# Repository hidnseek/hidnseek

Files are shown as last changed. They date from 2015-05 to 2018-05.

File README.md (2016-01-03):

# hidnseek
## The smart, Accurate GPS tracker on sigfox network
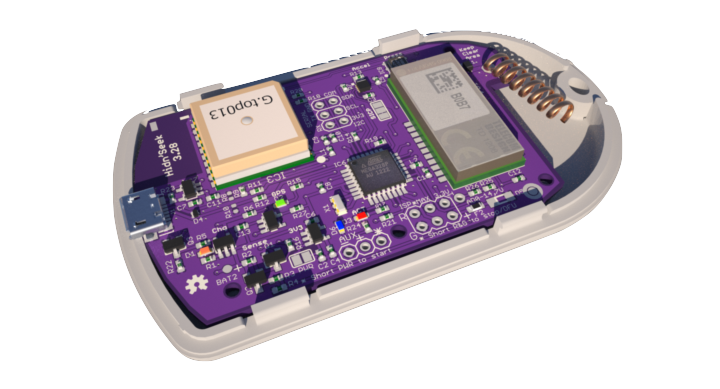
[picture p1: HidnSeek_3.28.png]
Inside Board View


* true GPS localisation
* 3 axis Motion sensor
* Temperature and Pressure data logger
* Several months autonomous
* Rechargeable and monitored battery
* Firmware update with onchip USB interface
* Geo Fencing with [Apple iOS](https://itunes.apple.com/fr/app/hidnseek/id1014592720?mt=8) and [Android](https://play.google.com/apps/testing/com.hidnseek.hidnseek) Application
* GPIOs available for future extensions (i2c, Serial, ISP, Analog input, Digital)

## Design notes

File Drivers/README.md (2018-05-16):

### Arduino IDE Setup

The first thing you will need to do is to download the latest release of the Arduino IDE. You will need to be using version **1.6.4** or higher for this guide.

[Arduino IDE v1.6.x](http://www.arduino.cc/en/Main/Software)

After you have downloaded and installed **v1.6.11**, you will need to start the IDE and navigate to the **Preferences** menu. You can access it from the **File** menu in Windows or Linux, or the **Arduino** menu on OS X.

A dialog will pop up and we will be adding a URL to the new **Additional Boards Manager URLs** option. The list of URLs is comma separated, and you will only have to add each URL once. New HidnSeek board and update to existing boards will automatically be picked up by the Board Manager each time it is opened. The URLs point to index files that the Board Manager uses to build the list of available & installed boards.
To find the most up to date list of URLs you can add, you can visit the list of [third party board URLs on the Arduino IDE wiki](https://github.com/arduino/Arduino/wiki/Unofficial-list-of-3rd-party-boards-support-urls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). We will only need to add one URL to the IDE in this example, but **you can add multiple URLS by separating them with commas**. Copy and paste the link below into the **Additional Boards Manager URLs** option in the Arduino IDE preferences.

[https://hidnseek.github.io/hidnseek/package_hidnseek_boot_index.json](https://hidnseek.github.io/hidnseek/package_hidnseek_boot_index.json)

Click **OK** to save the new preference settings. Next we will look at installing boards with the Board Manager.

### Installing Boards

Now that you have added the appropriate URLs to the Arduino IDE preferences, you can open the **Boards Manager** by navigating to the **Tools->Board** menu. Find and install **HidnSeek** board.

Next, **quit and reopen the Arduino IDE** to ensure that all of the boards are properly installed. You should now be able to select and upload to the new boards listed in the **Tools->Board HidnSeek** menu.

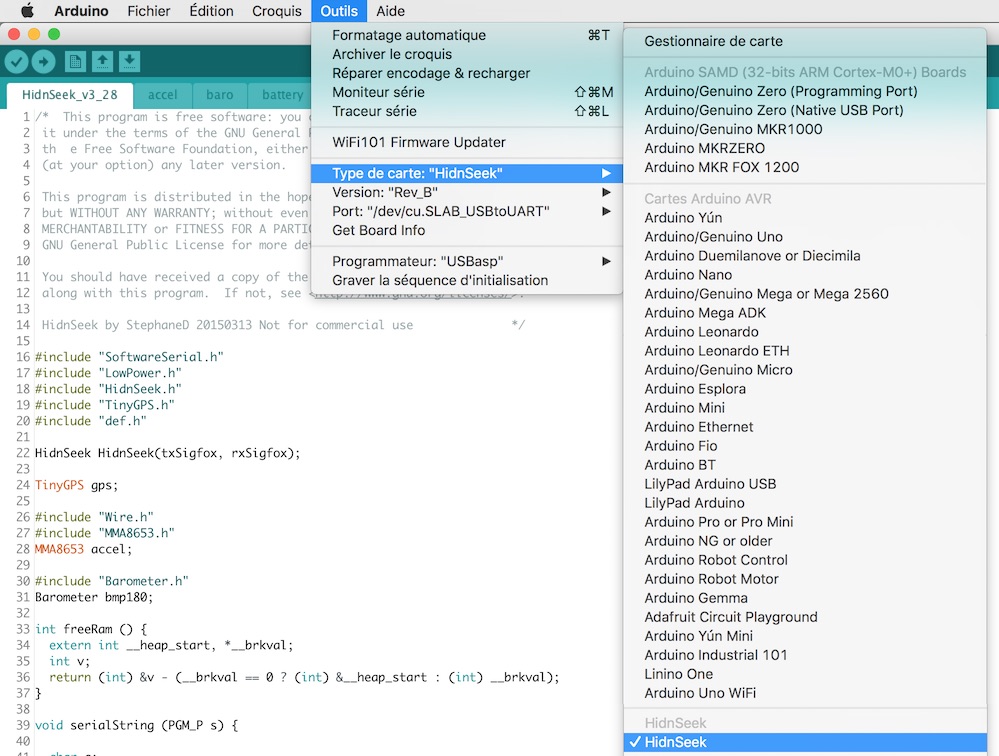
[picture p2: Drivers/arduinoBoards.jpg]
alt arduino Boards image


### USBasp Drivers for Windows
* **Windows up to 7.x** : [usbasp-windriver.2011-05-28.zip](usbasp-windriver.2011-05-28.zip)
* **Windows 8.1 to 10.x** : [USBasp-win-driver-x86-x64-v3.0.7.zip](USBasp-win-driver-x86-x64-v3.0.7.zip)

The USBASP windows driver was previously based on libusb-win32. The certificate on the base drivers have expired and the library has now been superseded by libusbK. Earlier today we packaged up the driver and uploaded it to the server. You can now download it from the location below.

 [http://www.protostack.com/download/USBasp-win-driver-x86-x64-v3.0.7.zip] (http://www.protostack.com/download/USBasp-win-driver-x86-x64-v3.0.7.zip)
 
This driver should work with version of Windows XP right through to 8.1 and the version 10 preview. (both 32 and 64 bit editions). Because the driver is signed, there should be no need to disable driver certificate enforcement or use Zadig.

### Update Febuary 16 to upgrade the firmware with hex provided on the website

first, power off the hidnSeek tracker (dance on manual page 16 or short circuit R&G pins)

* On Windows 10, install the executable version of [Arduino IDE v1.8.x](http://www.arduino.cc/en/Main/Software)
not the Windows App version.

* install the driver from Zadig [http://zadig.akeo.ie/downloads/zadig_2.2.exe] (http://zadig.akeo.ie/downloads/zadig_2.2.exe)

Launch the software, connect the tracker and click on the install button. It will detect the tracker and install correct drivers. Disconnect the tracker before Green LED start blinking, if it blink, power off again the tracker.

* Open a command windows (Win+X), go in the C:\Users\Program Files(x86)\Arduino\hardware\tools\avr\bin and prepare the command as above with a respect of the path of the hex file:

**avrdude -C ..\etc\avrdude.conf -p atmega328p -c usbasp -P usb -U flash:w:"C:\Users\[your path]\HidnSeek.hex":i**

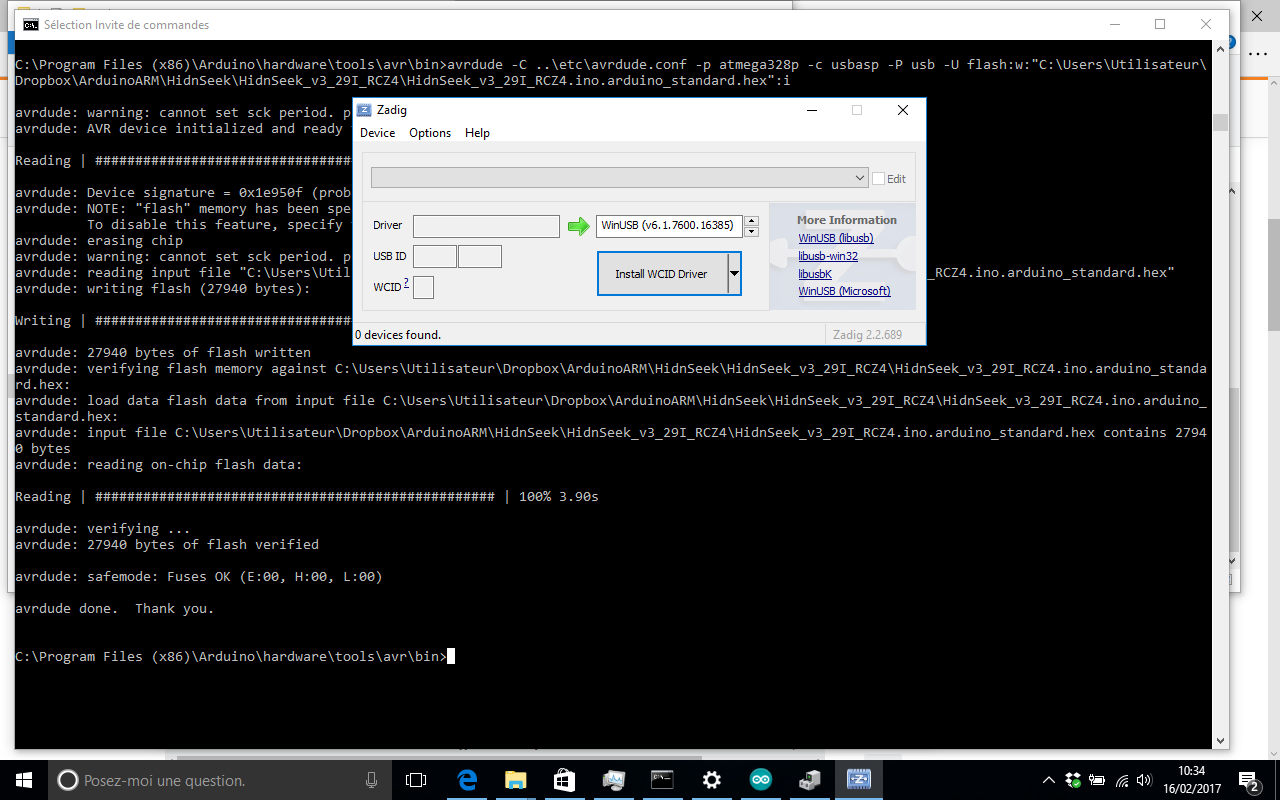
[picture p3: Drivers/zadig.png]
alt zadig image


When you are ready, connect the tracker to the USB port and launch the command. If there is an error, unplug the tracker to avoid to repeat the power off procedure.

### Reset manually the tracker

Unplug the USB connector, open the tracker and make a short-cut between R and G pins like the above picture.

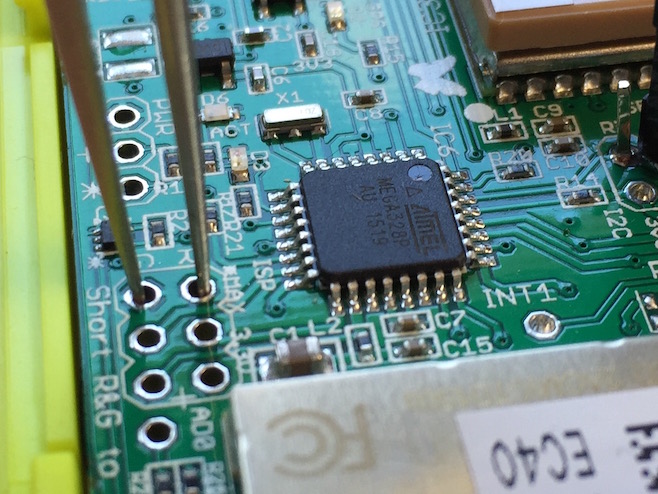
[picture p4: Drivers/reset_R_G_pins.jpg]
alt R and G picture hidnseek reset image


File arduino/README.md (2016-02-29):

#Arduino Hardware, source code and libraries

##Hardware : changes and needs for Arduino IDE 1.6.4 and higher
Go to the page [Drivers](/Drivers) in this repository and follow instructions

##Hardware : changes and needs for Arduino IDE

How to upload new firmware in Hidnseek ?

First install Arduino IDE (https://www.arduino.cc/en/Main/Software)
If Arduino IDE already installed, leave/exit the software.

Second, find in the installation directory the boards.txt file

* /Applications/Arduino.app/Contents/Java/hardware/arduino/avr/boards.txt (Mac)
* c:\Documents and Settings\<USERNAME>\Application Data\Arduino\hardware\arduino\avr\boards.txt (Windows XP)
* c:\Users\<USERNAME>\AppData\Roaming\Arduino\hardware\arduino\avr\boards.txt (Windows Vista)
* ~/.arduino/hardware/arduino/avr/boards.txt (Linux)

Insert at the end of this file the description of HidnSeek from [boards.txt](/Drivers/Hardware/boards.txt) 

##libraries : librairies used to compile the sketch

Copy all libraries in this repository that are not present in your libraries directory

##HidnSeek Sketch Examples

Launch Arduino IDE and go to the board selection and select HidnSeek at 12MHz

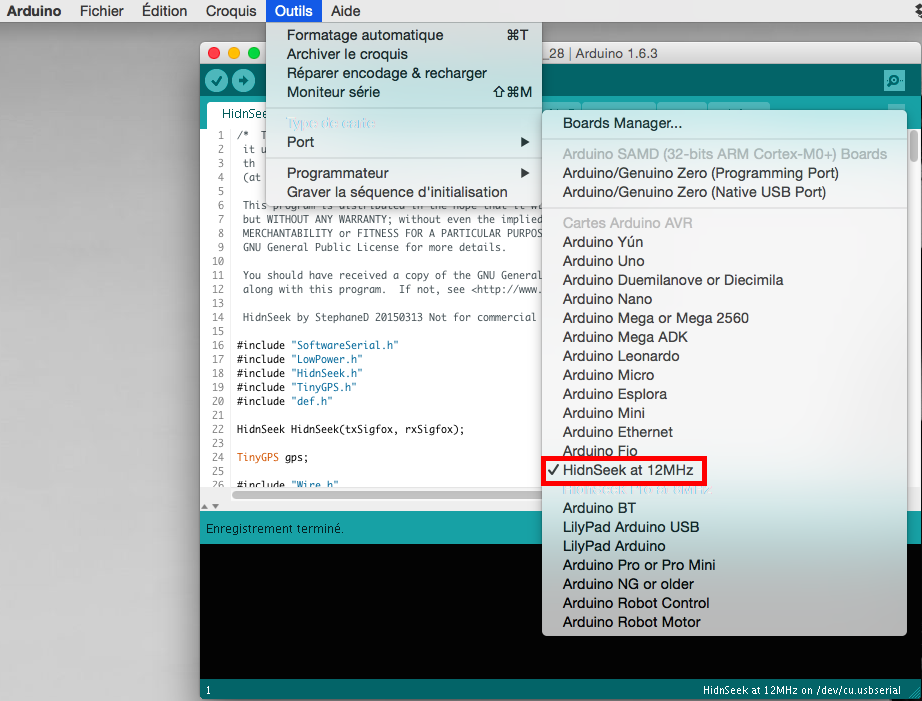
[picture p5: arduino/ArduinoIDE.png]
ArduinoIDE


Then select the programmator type USBasp

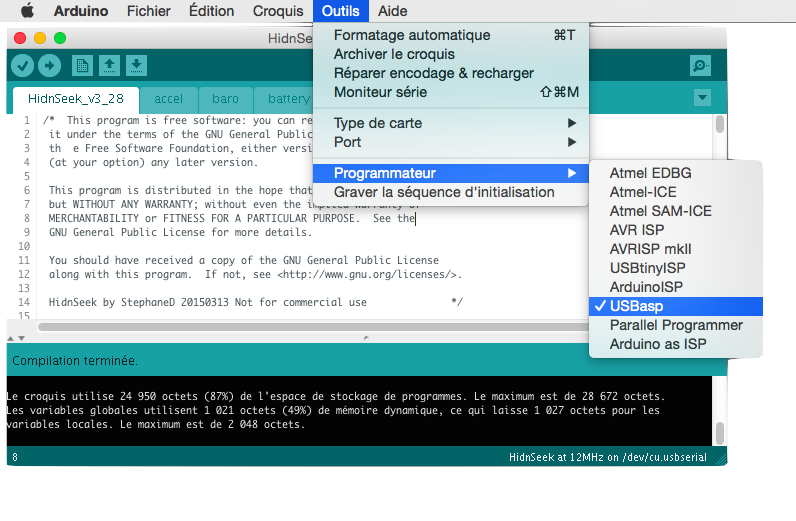
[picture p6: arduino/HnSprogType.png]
HnSprogType


Go to the Examples and select one of available in the HidnSeek tree (BlinkWithin30seconds, HidnSeek_v3_28 and detectMotion)

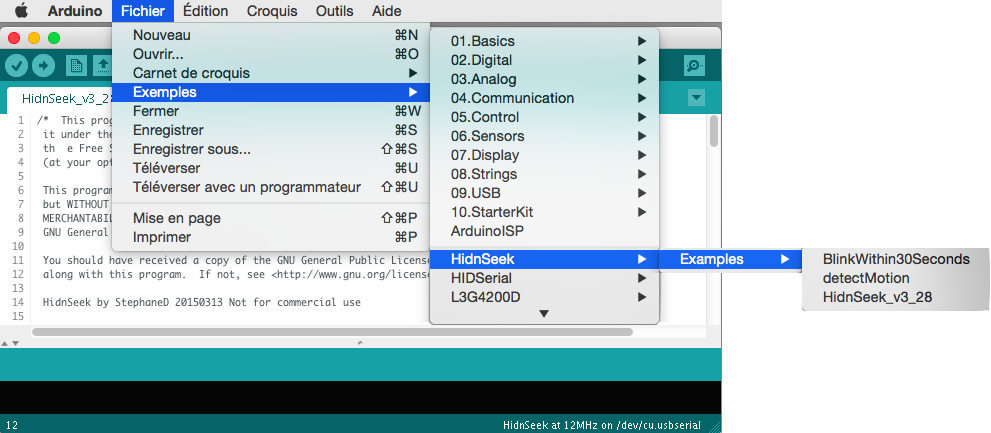
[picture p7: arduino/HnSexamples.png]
Examples


###HidnSeek_v3_28 of the 3.28 release board:
Load the sketch HidnSeek_v3_28 and compile it. The code size must be 24 950 bytes and available memory is 1027 bytes

There is two methods to prepare HidnSeek for DFU mode (firmware update)

1. make the dance that you can find on the manual or [FAQ](https://www.hidnseek.fr/faq)
2. make a short circuit between R & G pins (you will loose daily statistics)

Once it's done, you can plug the USB cable to the computer and the HidnSeek board.
You will see between 30 and 60 red LED flashes to notice that you are in DFU mode. Click on download on your sketch windows.
Firmware update will be transfered in less than 4 seconds. Do not care about the clk speed warning.
Your sketch is ready to start after the booting time (0-30) seconds

Have fun !

## Serial debugging

You can plug a USB Serial TTL dongle and get debug output from HidNseek on pin TX and output from GPS on RX. 

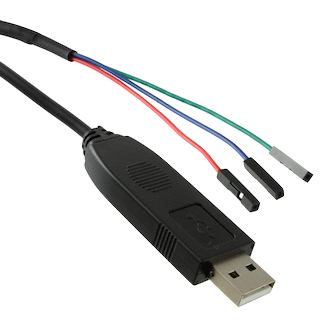
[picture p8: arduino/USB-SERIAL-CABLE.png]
USB cable
 | If GPS is not enabled, its output is floating and you can use that state to send serial data to HidnSeek **at 3,3V maximum !!!!**
------------- | -------------

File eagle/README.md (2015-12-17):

# hidnseek

Eagle libray for the HidnSeek and droneRescue Projects

- MMA8653 Freescale Accelerometer
- Molex 47346 Micro USB Connector
- Atmega 328p MLF32 Package with small Thermal Pad
- Murata Super Capacitor DMF3 Series
- Taiyo Yuden Coin Cell Super Capacitor
- Telecom Design TD120x SigFox Internet of Things Modem
- TPS2513 Texas Instrument Current Limited USB Charger Controller
- TPS2294x Texas Instrument Current Limited Power Switch

# Telecom Design breakout board
schematic and layout for Eagle software

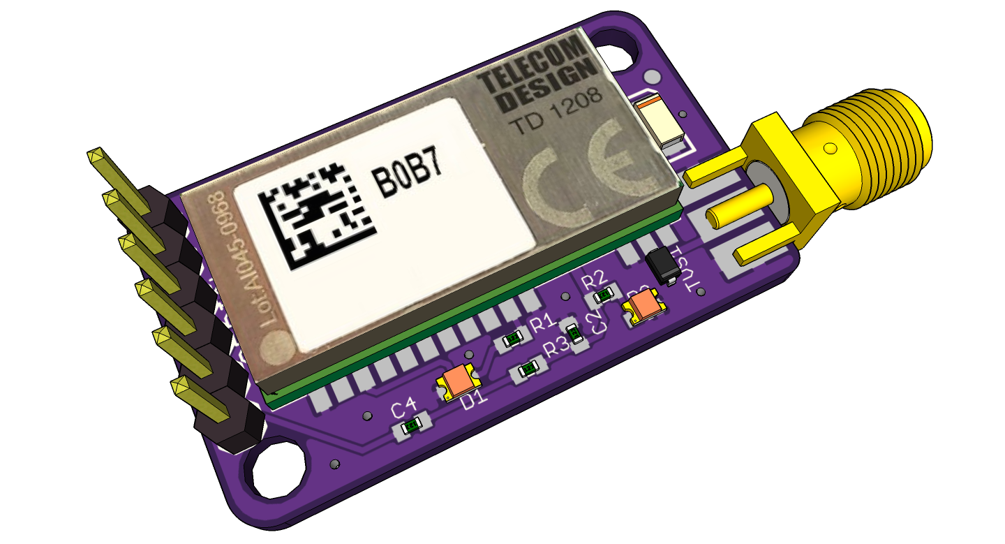
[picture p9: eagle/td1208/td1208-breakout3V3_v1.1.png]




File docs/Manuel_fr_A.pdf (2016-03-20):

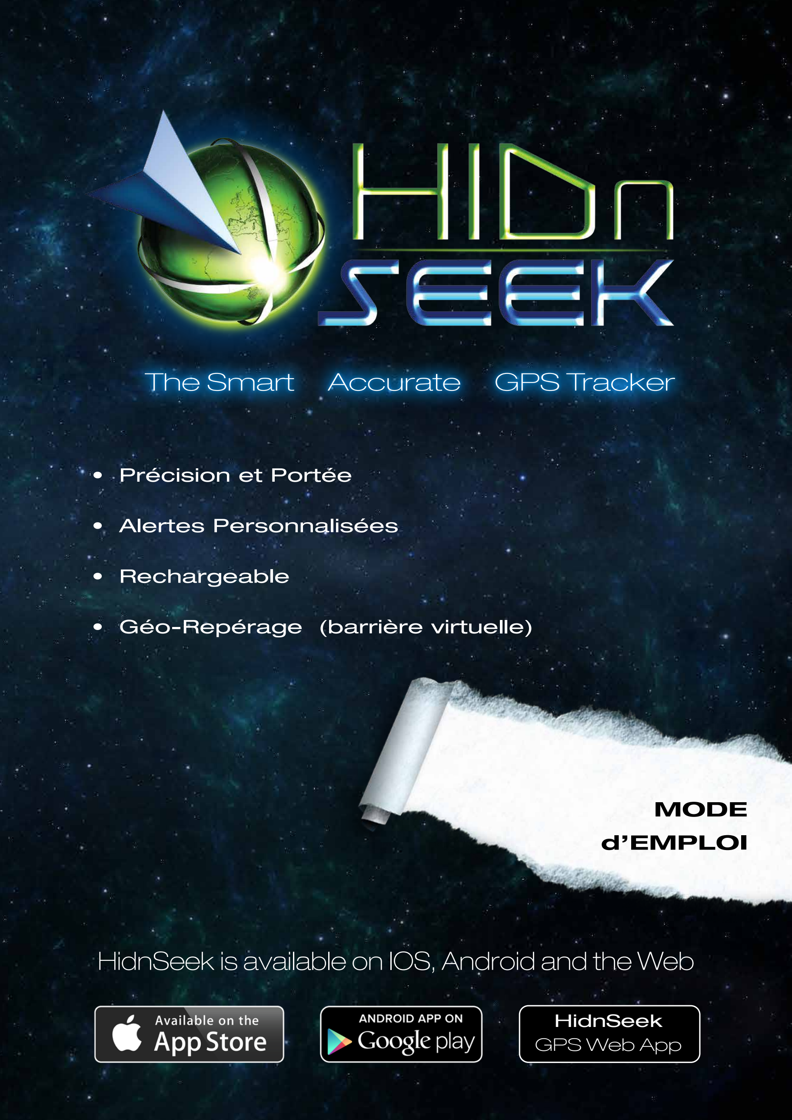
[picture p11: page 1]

## The Smart Accurate GPS Tracker

### MODE d’EMPLOI

## HidnSeek is available on IOS, Android and the Web

HidnSeek
GPS Web App
- Précision et Portée
- Alertes Personnalisées
- Rechargeable
- Géo-Repérage (barrière virtuelle)

# CONTENTS

Informations importantes concernant votre appareil. Compatibilité électromagnétique
Risques pour les enfants et les personnes ayant besoin de soins
Conseils de sécurité
Fonctionnement de la batterie
Disposition
Fonctions et utilisation
Déclaration de conformité
Rayonnement de la CE de la déclaration de l'exposition
CE radiation exposure statement
RSS (catégorie | équipement)

Guide d'installation rapide

Commencer
Se charge
Activation
L'App

Smartphone App Utilisation Se connecter
Rajout / Eacer un Device
Location
Ecran d’information HidnSeek Conguration des Alertes
Renommez dispositif
Niveau de la batterie
Détection de mouvement
Géo-Barrière (Geo-fencing) Créer un Géo-fence
Eacer un Géo-fence
Paramètres Géo-fencing
Ecran d’Alertes

Mise HidnSeek Arrêt / Marche

Mode Sport

Presentation de votre appareil

LED et état de l'appareil

Soutien

Page 3

Page 4

Page 5

Page 6

Page 7

Page 8

Page 9

Page 10
Page 11
Page 12

Page 13

Page 14

Page 15

Page 16

Page 17

Page 18

## INFORMATIONS IMPORTANTES

CONCERNANT VOTRE APPAREIL.

COMPATIBILITÉ ÉLECTROMAGNÉTIQUE
Les champs magnétiques intensifs (par ex. des transformateurs) doivent être strictement évités, sinon des écarts dans la transmission peuvent apparaître. Ignorer les instructions d’utilisation peut entraîner une perturbation ou des dommages du dispositif de repérage GPS HidnSeek.

DANGERS POUR LES ENFANTS ET LES PERSONNES AYANT DES CAPACITÉS RÉDUITES
Cet appareil n’est pas destiné à être utilisé par des personnes (y compris les enfants) ayant des capacités physiques, sensorielles ou mentales limitées, ou manquant d’expérience et/ ou de connaissances, sauf si elles sont surveillées par une personne responsable de leur sécurité ou ont reçu des instructions sur la façon d’utiliser cet appareil.

RENSEIGNEMENTS SUR LA SÉCURITÉ
Attention: Bien que le dispositif de repérage HidnSeek soit petit et de faible poids, il peut être trop lourd pour hurter les enfants ou animaux.

MODE BATTERIE
Le dispositif de repérage HidnSeek fonctionne avec une batterie au lithium-polymère rechargeable intégrée qui ne peut pas être échangée:
- La batterie du dispositif de repérage GPS HidnSeek ne peut pas être échangée et ne doit pas être retirée.
- Ne laissez pas le dispositif de repérage GPS HidnSeek à proximité d’une source de chaleur ou dans un lieu où la température est très élevée, par exemple dans un véhicule stationné en plein soleil.
- Le dispositif de repérage GPS HidnSeek ne doit pas être percé ou brûlé.
- Chargez la batterie exclusivement avec le câble USB fourni. Si la batterie est chargée différemment, une surchauffe, un incendie ou une explosion peuvent être provoqués.
- Ne chargez pas la batterie du dispositif de repérage GPS Tractive à proximité d’une source de chaleur ou dans une voiture stationnée en plein soleil. La température élevée peut provoquer la destruction de la batterie et peut causer une surchauffe, une explosion ou un feu.
Le non-respect de ces instructions peut raccourcir la durée de vie de la batterie intégrée ou endommager le dispositif de repérage HidnSeek.

RENSEIGNEMENT: Dans certains pays et régions, il y a des lois sur le positionnement numérique et le suivi des personnes, des animaux et/ou des objets. Seul l’utilisateur du dispositif de repérage GPS HidnSeek, est responsable de ne pas violer ces lois ou règles. HidnSeek ne peut en aucun cas porter cette responsibilité.used.

DISPOSITION
Les batteries usagées sont considérées comme des déchets dangereux. Si vous souhaitez jeter la batterie, veuillez vous rendre chez un revendeur de piles ou dans des endroits de collecte qui mettent à votre disposition des collecteurs réservés à cet effet. Si vous souhaitez jeter votre appareil, éliminez-le selon la réglementation actuelle. Vous pouvez obtenir des renseignements relatifs au recyclage des batteries auprès des municipalités.

FONCTIONS ET UTILISATION
Afin de permettre la localisation des personnes ou possessions, vous avez besoin d’un ordinateur avec accès à l’Internet et/ou d’un Smartphone (Android, iPhone) ainsi que l’application HidnSeek GPS correspondante, disponible dans l’Apple App Store ou sur Google Play Store. Le dispositif de repérage GPS HidnSeek peut être utilisé seulement après l’activation réussie sur un navigateur.

AFIN DE RESPECTER LES AUTORITES AERONOTIQUE, ETEINDRE VOTRE HIDNSEEK AVANT LE DECOLLAGE CAR CELUI-CI PEUT CAUSER DES INTERFERENCES ELECTROMAGNETICS AUX SYSTEMES DE NAVIGATION DE L’AVION.

HIDNSEEK EST UN APPAREIL “SIGFOX READY” QUI A BESOIN DU RESEAU SIGFOX POUR FONCTIONNER

DÉCLARATION DE CONFORMITÉ
EMC Directive 1999/519/CE:
Texte court de la déclaration: HidnSeek déclare que le dispositif de repérage GPS est conforme aux exigences essentielles et aux autres dispositions pertinentes de la directive 1999/519/CE.
EN 60950-1 (2006+A11/2009+A1/2010+A12/2011) IEC 60950-1 (2005+A1/2009) ETSI EN 300 220-1 V2.4.1 (2012)
ETSI EN 300 220-2 V2.4.1 (2012)
RECOMMENDATION DU CONSEIL N° 1999/519/CE of 12 July 1999
ETSI EN 301 489-1 (V1.9.2) - ETSI EN 301 489-3 (V1.6.1)

CE CERTIFICATION
Ce produit repond aux regles CE. Son fonctionnement est soumis aux 2 conditions suivantes:
1. Ce dispositif ne peut causer des interférences nuisibles et
2. Cet appareil doit accepter toute interférence reçue, y compris les interférences qui peuvent entraîner un mauvais fonctionnement de l’appareil.

AVERTISSEMENT: Les changements ou modifications de cette unité non expressément approuvés par le partie responsable de la conformité pourraient annuler l'autorité de l'utilisateur à utiliser cet équipement.

NOTE: Cet équipement a été testé et trouvé conforme aux limites pour ETSI EN 300 220-1 V2.4.1 (2012), ETSI EN 300 220-2 V2.4.1 (2012), en vertu de la règles CE. Ces limites sont conçues pour fournir une protection raisonnable contre les interférences nuisibles dans une installation résidentielle. Cet équipement génère, utilise et peut rayonner de l'énergie radiofréquence et, si non installé et utilisé en conformité avec les instructions, peut causer des interférences nuisibles aux communications radio. Cependant, il n'y a aucune garantie que l'interférence ne se produira pas dans une installation articuliere. Si cet équipement cause des interférences nuisibles à la réception radio ou la télévision, l'utilisateur est encouragé à essayer de corriger l'interférence par une ou plusieurs des mesures suivantes les mesures:
- Réorienter ou déplacer le tracker GPS,
- Augmenter la séparation entre l'équipement et le récepteur.
- Consulter le revendeur ou un technicien radio / TV expérimenté.

CE EXPOSITION AUX RADIATIONS
Cette exigence est conforme aux limites d'exposition aux radiations définies par la norme CE pour un environnement non contrôlé. Cet équipement doit être installé et utilisé avec distance minimum de 20cm entre le radiateur et votre corps. Cet émetteur ne doit pas être co-localisées ou opérant en conjonction avec tout autre antenne ou émetteur.

RSS (EQUIPEMENT I CATEGORIE)
Cet appareil est conforme avec Industrie France licence - standard RSS exonéré (s). Son fonctionnement est soumis aux deux conditions suivantes:
1. ce dispositif ne peut pas provoquer d'interférences et
2. ce dispositif doit accepter toute interférence, y compris les interférences qui peuvent causer un fonctionnement indésirable de l'appareil.

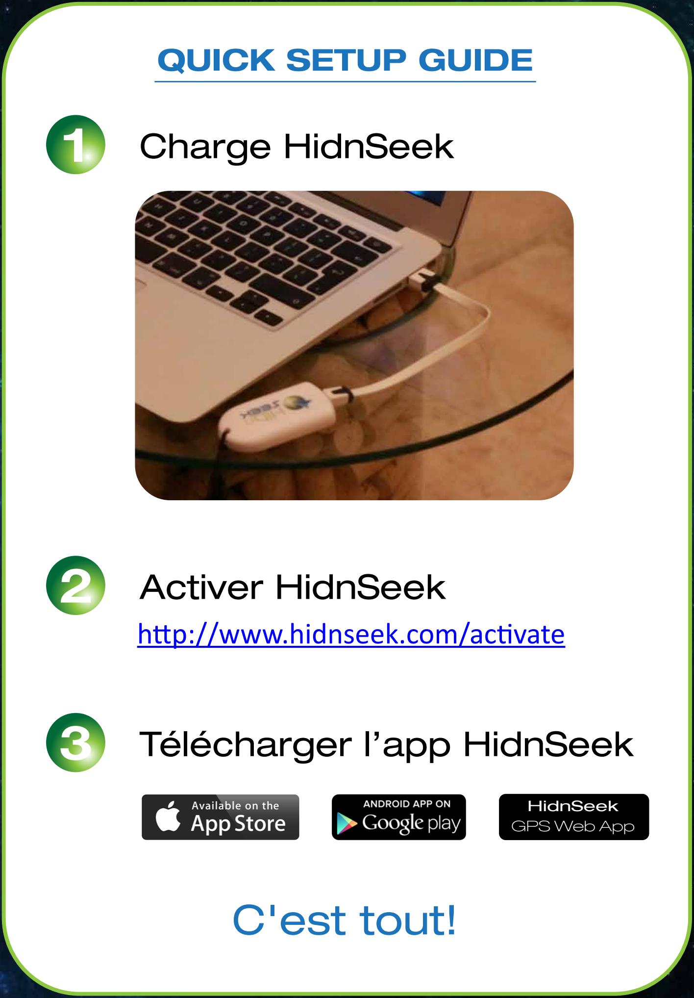
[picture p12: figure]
1 Charge HidnSeek; 2 Activer HidnSeek; 3 Télécharger l’app HidnSeek; QUICK SETUP GUIDE; C'est tout!; HidnSeek GPS Web App; http://www.hidnseek.com/activate

1

2

3

# COMMENCER

## COMPOSANTS DE LA COMMANDE 1 HidnSeek GPS Device 1 USB Charging Cable

## Se charge

Nous recommandons de charger l’appareil complètement avant la première utilisation. Branchez le câble micro-USB de chargement fourni avec l’appareil et connecter le cable sur votre PC pour recharger votre HidnSeek.

Lorsque votre produit HidnSeek est en charge une LED jaune s’allume. Lorsque votre HidnSeek est completement recharge la LED jaune s’etteind.

## Activer HidnSeek Pour activer le dispositif, il faut que l’appareil soit

allumé.

## Insérez le lien suivant dans la barre d’adresse de votre navigateur et rendez vous sur le site Internet d’HidnSeek, qui vous conduira étape par étape pour activer votre dispositif de repérage GPS HidnSeek:

## L'App Pour télécharger l'application à partir de l'iPhone d'Apple, charger l'iTunes App Store et de recherche pour 'HidnSeek'. Alternativement, si vous utilisez un Android, ouvrir le Google Play Store et commencer

une recherche pour 'HidnSeek'.

## http://www.hidnseek.com/activate

# SMARTPHONE APP UTILISATION

REJOINDRE | HIDNSEEK | –

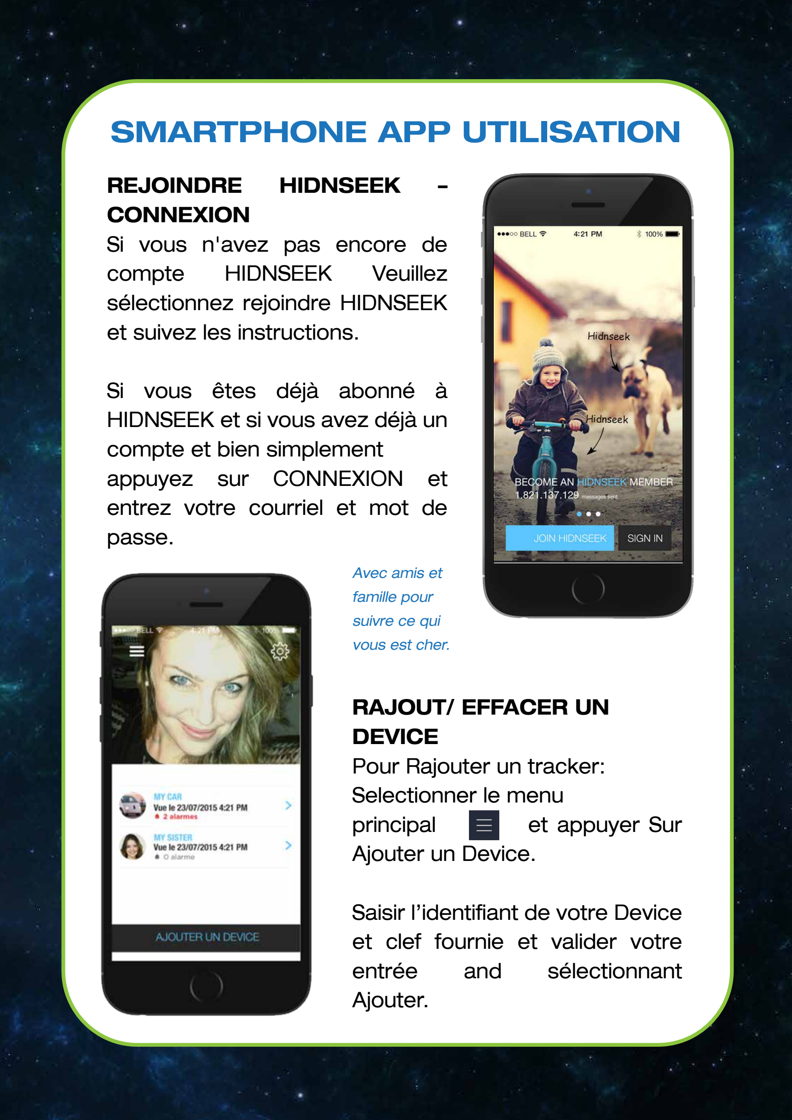
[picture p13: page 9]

## CONNEXION Si vous n'avez pas encore de

compte | HIDNSEEK | Veuillez

## sélectionnez rejoindre HIDNSEEK

et suivez les instructions.

## Si vous êtes déjà abonné à HIDNSEEK et si vous avez déjà un compte et bien simplement appuyez sur CONNEXION et entrez votre courriel et mot de

passe.

## RAJOUT/ EFFACER UN DEVICE Pour Rajouter un tracker: Selectionner le menu

principal | | et appuyer Sur
Ajouter un Device.

## Saisir l’identifiant de votre Device et clef fournie et valider votre

entrée | and | sélectionnant
Ajouter.

Avec amis et
famille pour
suivre ce qui
vous est cher.

## LOCATION

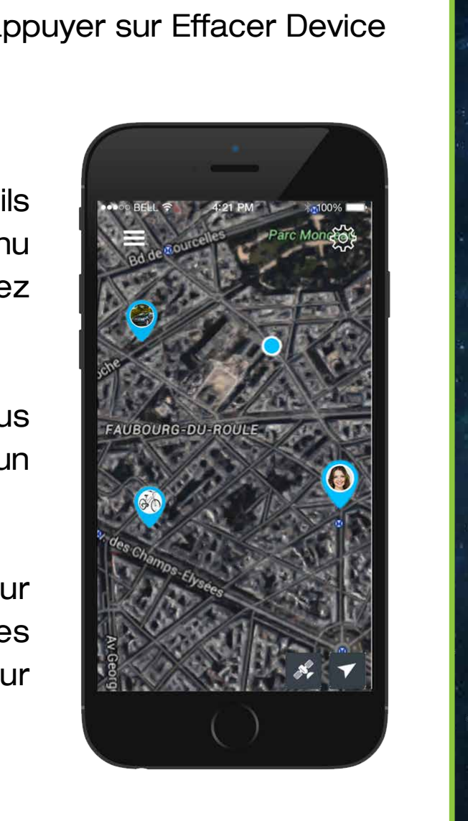
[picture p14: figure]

## Pour voir tous vos appareils simplement aller dans le Menu

principal | et sélectionnez
Location.

## Automatiquement l'écran vous affichera tous vos appareils en un

clein d’oeil.

## En appuyant sur un marqueur vous pouvez visualiser des informations récapitulatives sur votre appareil, y compris :

Alt (Altitude),
Cap (Direction),
Sp (Vitesse),
Bat (Niveau batterie).

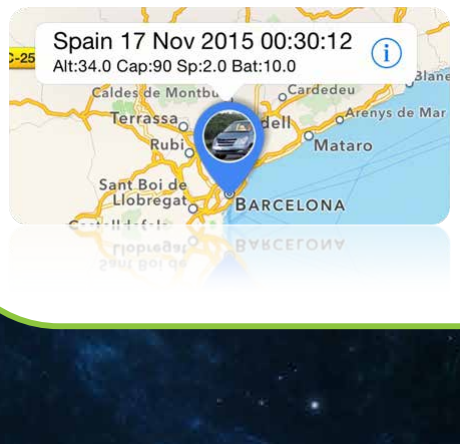
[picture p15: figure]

## Appuyez sur pour afficher l'écran d'information avancées

de votre tracker.

## Pour effacer un Device:

Selectionner le menu principal | et selectionner un
Device, puis appuyer sur | puis taper sur le Device

## que vous souhaitez Effacer et appuyer sur Effacer Device

au bas de la page.

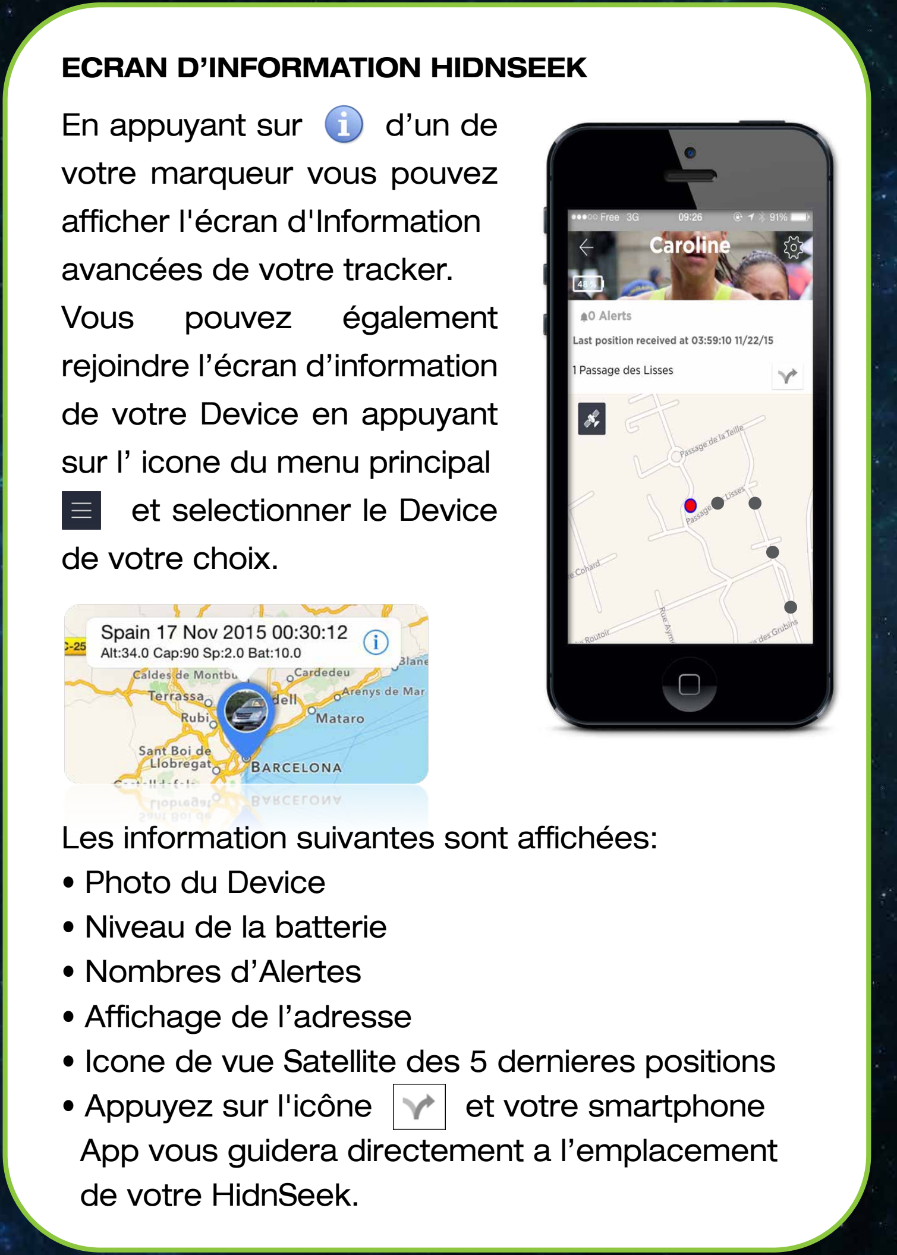
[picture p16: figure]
En appuyant sur; votre marqueur vous pouvez afficher l'écran d'Information avancées de votre tracker.; Vous; pouvez; également; rejoindre l’écran d’information de votre Device en appuyant sur l’ icone du menu principal et selectionner le Device de votre choix.; • Photo du Device • Niveau de la batterie • Nombres d’Alertes • Affichage de l’adresse; de votre HidnSeek.; ECRAN D’INFORMATION HIDNSEEK

## Les information suivantes sont affichées:

## - Icone de vue Satellite des 5 dernieres positions - Appuyez sur l'icône et votre smartphone App vous guidera directement a l’emplacement

## RENOMMEZ DISPOSITIF De votre menu Device

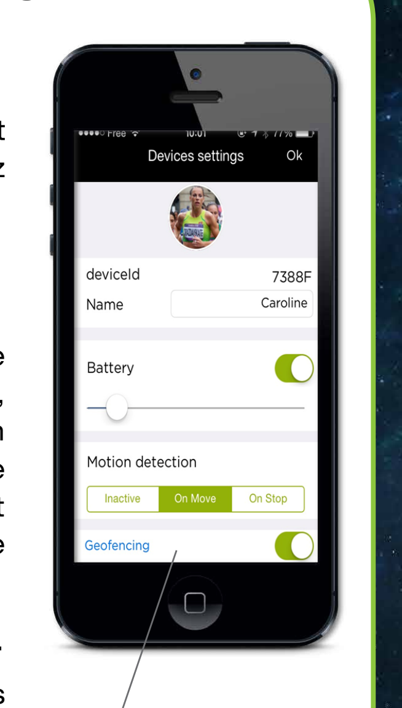
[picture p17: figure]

selectionner | un | Device | et
appuyer sur | vous pouvez

## alors changer le nom de votre

HidnSeek.

## NIVEAU DE BATTERIE Pour définir une alerte pour le

niveau | de | votre | batterie,

## simplement taper sur le bouton de la batterie pour activer le monitoring de son état et sélectionner le niveau d’alerte

désiré.

## DETECTION DE MOUVEMENT Sélectionnez l’une des options d’alertes pour recevoir une notification dans le cas ou votre HidnSeek bouge ou au contraire

s’immobilise.

## GÉO-BARRIÈRE (GEO-FENCING) Tapez sur géofencing au bas du menu paramètres de

configuration.

## CONFIGURATION DES ALERTES

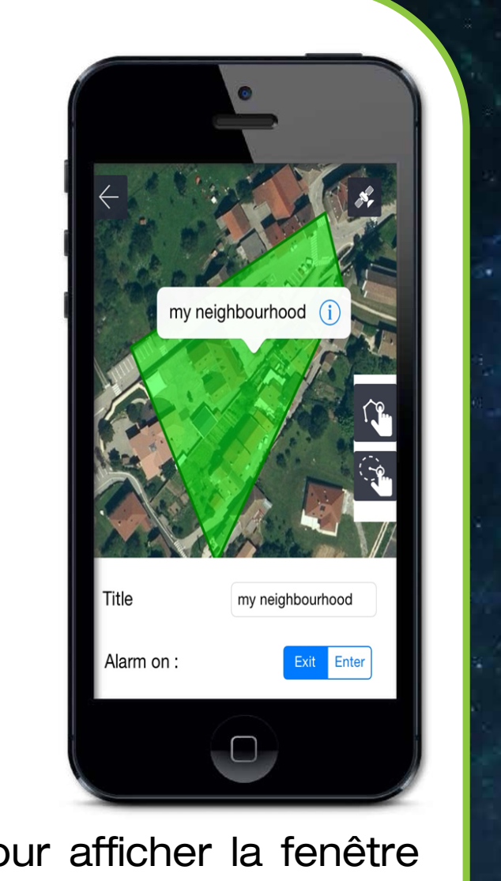
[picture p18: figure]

## CRÉER UN GÉO-FENCE Faire un zoom de la zone ou vous voulez créer un géo-fence. Tracer un géofence en utilisant les options suivantes: - Point a point géo-fence - radius géo-fence

## EFFACER UN GÉO-FENCE

Touchez | et | faites | glisser | la

## géo-barrière vers le bas de l'écran où vous pourrez voir la zone

nommée Drop here to delete.

## PARAMÈTRES GÉO-FENCING

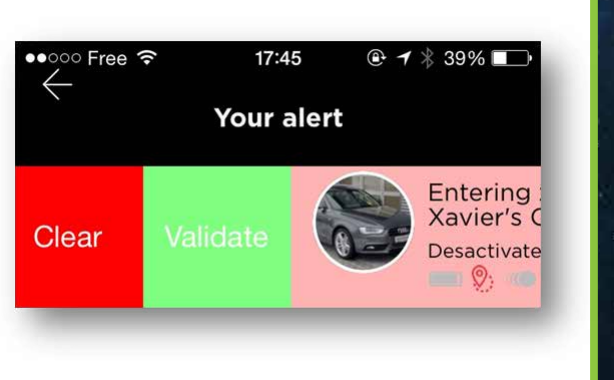
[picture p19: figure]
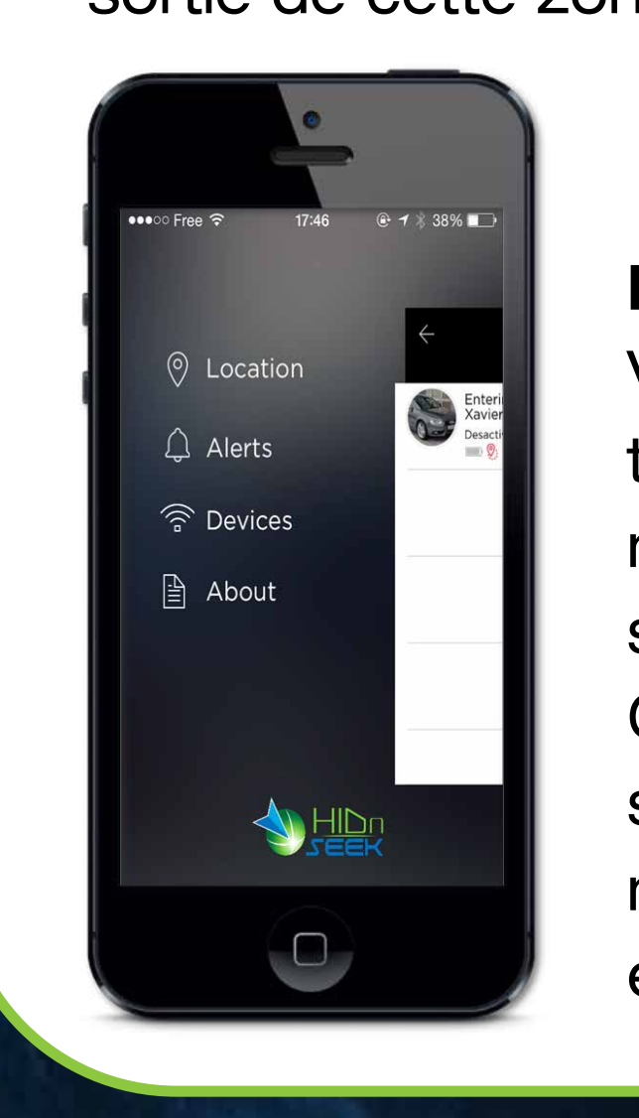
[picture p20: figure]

## ECRAN D’ALERTES Vous trouverez toutes vos alertes en

tapant le bouton alertes | dans le

## menu principal. Une alerte non validée

s'affiche sur fond rouge.
Glissez | le | message | d'alerte | et

## sélectionnez Validate pour reconnaître la notification ou sélectionnez Clear pour

effacer la notification complètement.

## Tapez sur la zone de surveillance pour afficher la fenêtre d'informations. Entrez un nom de votre zone de surveillance géographique et selectionner si vous souhaitez avoir une notification à l'entrée ou en

sortie de cette zone.

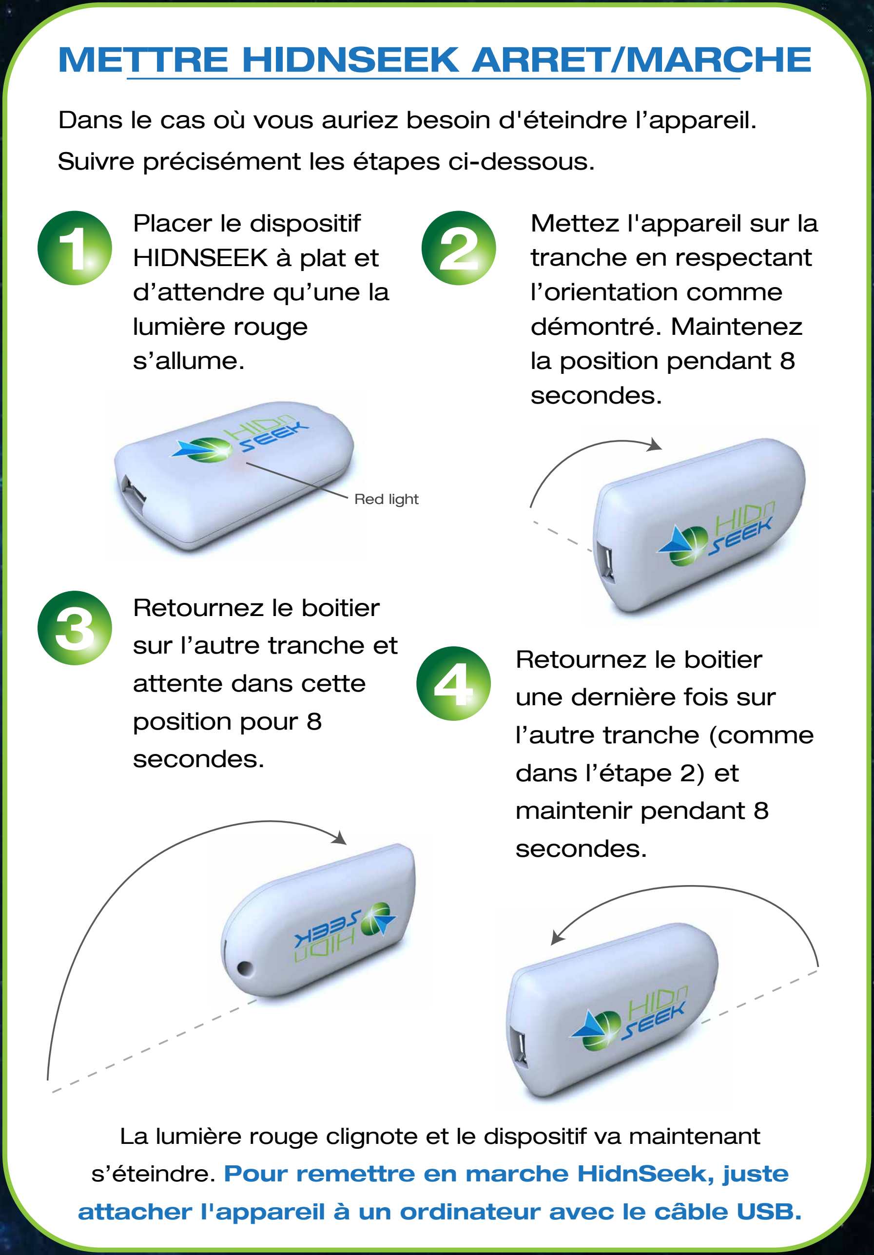
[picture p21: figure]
METTRE HIDNSEEK ARRET/MARCHE; Retournez le boitier sur l’autre tranche et attente dans cette position pour 8 secondes.; Retournez le boitier une dernière fois sur l’autre tranche (comme dans l’étape 2) et maintenir pendant 8 secondes.; Mettez l'appareil sur la tranche en respectant l’orientation comme démontré. Maintenez la position pendant 8 secondes.; Suivre précisément les étapes ci-dessous.; Red light; Placer le dispositif HIDNSEEK à plat et d’attendre qu’une la lumière rouge s’allume.

Dans le cas où vous auriez besoin d'éteindre l’appareil.

La lumière rouge clignote et le dispositif va maintenant s’éteindre. Pour remettre en marche HidnSeek, juste attacher l'appareil à un ordinateur avec le câble USB.

1 2

3
4

## METTRE HIDNSEEK EN MODE SPORT

Placer le dispositif à
plat sur son dos après
8 secondes HidnSeek
basculera en mode
sport.

HidnSeek par défaut, fonctionne en mode intelligent, ce qui signifie qu’il envois des positions lorsque le produits est en mouvement et Il ne peut le faire aussi souvent que toutes les 10 minutes.
En Mode Sport Le GPS HidnSeek reste actif lui permettant de maximiser la detection des satelites indépendamment de détection d'un mouvement. Ce mode reste actif pendant 4 heures et avant de repasser en mode intelligent.
REMARQUE: Le mode Sport videra votre batterie beaucoup plus vite!

Red light

Retournez le boitier
sur l’autre tranche et
attente dans cette
position pour 8
secondes.

Mettez l'appareil sur la
tranche en respectant
l’orientation comme
démontré. Maintenez
la position pendant 8
secondes.

Placer le dispositif
HIDNSEEK à plat et
d’attendre qu’une la
lumière rouge
s’allume.

## PRESENTATION DE VOTRE APPAREIL

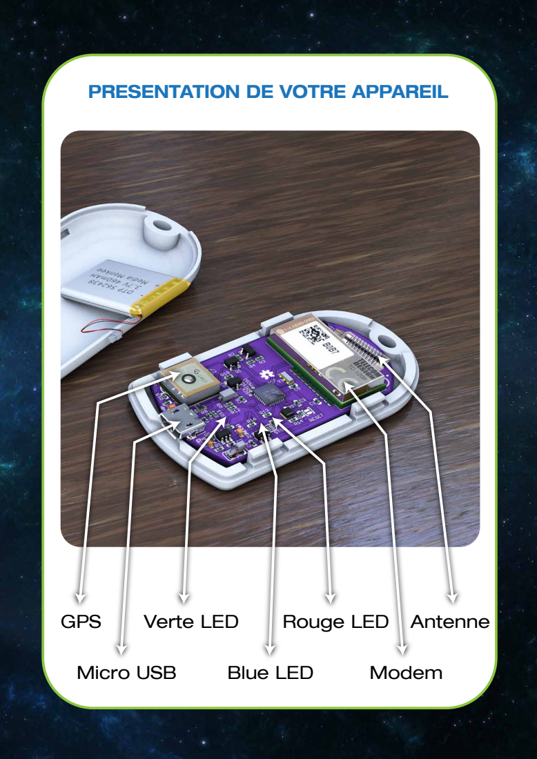
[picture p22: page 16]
GPS; Micro USB; Modem; Verte LED; Blue LED

Rouge LED Antenne

## LED AND DEVICE STATUS

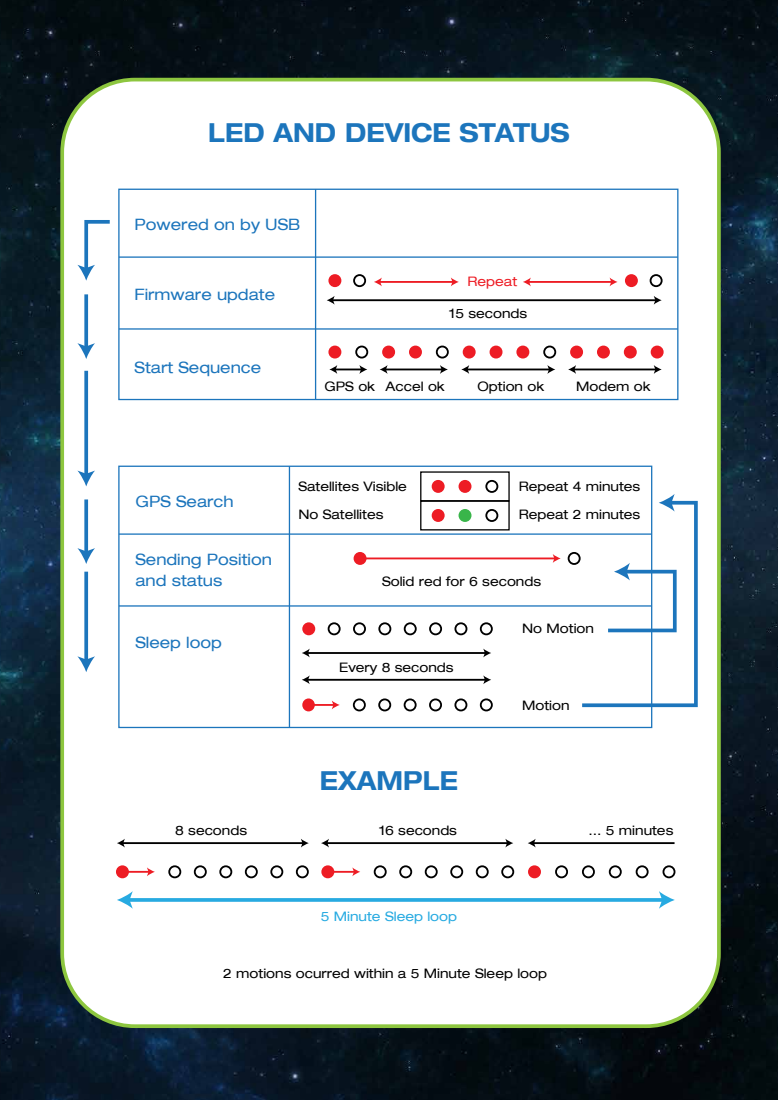
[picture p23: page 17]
EXAMPLE; Firmware update; Start Sequence; GPS Search; Sleep loop; Sending Position and status; 15 seconds; Every 8 seconds; 8 seconds; 16 seconds; ... 5 minutes; Repeat; GPS ok; Satellites Visible; No Satellites; No Motion; Motion; Accel ok; Option ok; Modem ok; Repeat 4 minutes; Repeat 2 minutes

Powered on by USB

Solid red for 6 seconds

5 Minute Sleep loop

2 motions ocurred within a 5 Minute Sleep loop

## SUPPORT

Si vous avez une question ou souhaitez soumettre un commentaire, vous avez les options suivantes:

a) Lisez les questions fréquemment posées (FAQs)
b) Contactez votre point de vente
c) Envoyer un email a:

VEUILLEZ NOTER QUE LES COLIS NON AFFRANCHIS ET NON PRÉVUS NE SERONT PAS ACCEPTÉS, POUR DES QUESTIONS D’ORGANISATION.

contact@hidnseek.fr

http://www.hidnseek.com/faq

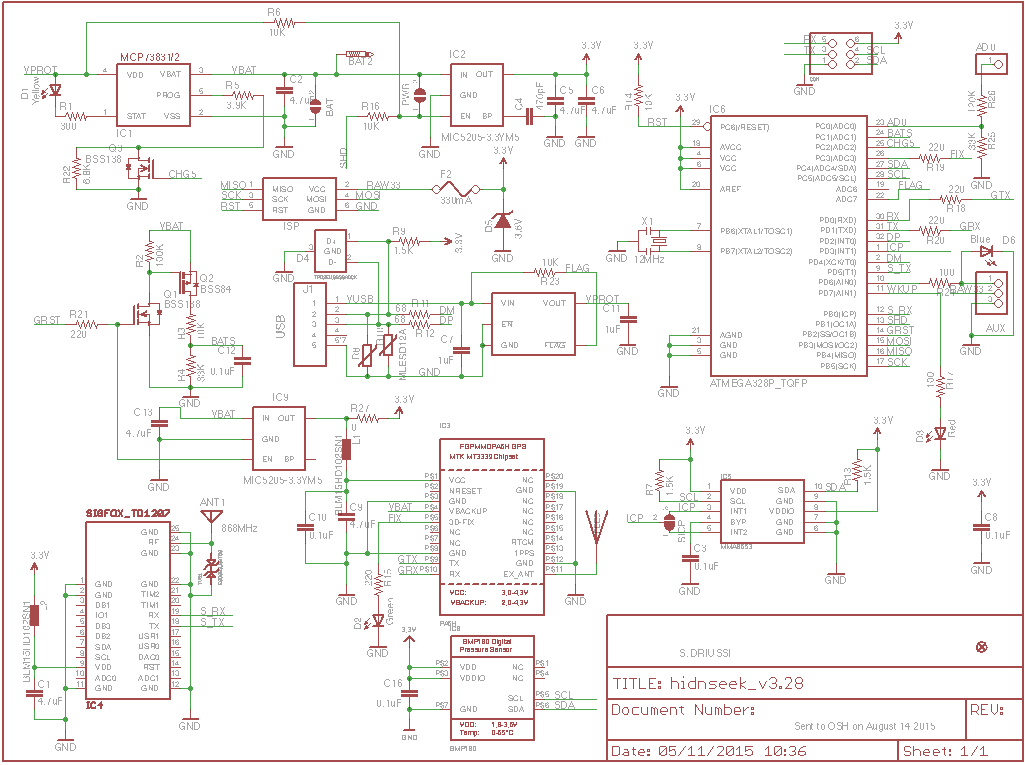
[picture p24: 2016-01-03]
eagle/Schematic_3.28.png

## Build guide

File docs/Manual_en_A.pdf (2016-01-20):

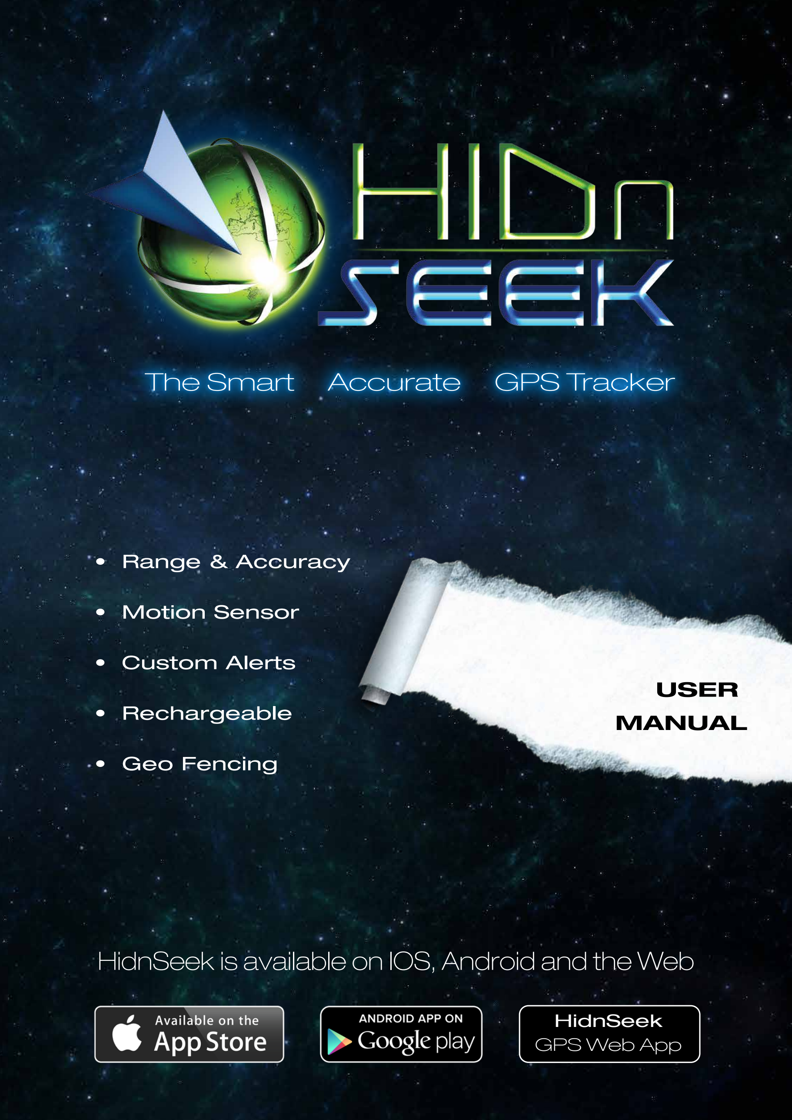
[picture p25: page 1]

## The Smart Accurate GPS Tracker

### USER MANUAL

- Range & Accuracy
- Motion Sensor
- Custom Alerts
- Rechargeable
- Geo Fencing

## HidnSeek is available on IOS, Android and the Web

HidnSeek
GPS Web App

# CONTENTS

Important Information about your device Electromagnetic Compatibility
Risks for children and people in need of care Safety Advice
Battery Operation
Disposal
Functions and use
Declaration of conformity
CE compliance statement
CE radiation exposure statement
RSS (category | equipment)

Quick Setup Guide

Getting Started
Charging
Activation
The app

Using the Smartphone App
Sign in
Add/ Delete device
Location
Advanced information screen Device and Alert settings
Rename device
Battery level
Motion detection
Geo-fencing
Create a Geo-fence
Delete a Geo-fence
Geo-fence settings
Alerts screen

Turning HidnSeek O/ On

Sport Mode

Device Components

LED and device status

Support

Page 3

Page 4

Page 5

Page 6

Page 7

Page 8

Page 9

Page 10
Page 11
Page 12

Page 13

Page 14

Page 15

Page 16

Page 17

Page 18

## IMPORTANT INFO ABOUT YOUR DEVICE

ELECTROMAGNETIC COMPATIBILITY
Very strong magnetic fields (e.g. transformers) should always be avoided as this may result in variations in the transmission. Failure to follow these instructions may lead to malfunctions or damage to your HidnSeek GPS device.

RISKS FOR CHILDREN AND PEOPLE IN NEED OF CARE
The use of this device is not intended for people (including children) with limited physical, sensory or mental abilities or lack of experience and/or lack of knowledge, unless they are supervised by a person responsible for their safety or have been instructed on the use of the device.

SAFETY ADVICE
Important: Although the HidnSeek GPS device is small in size, it might be too large or heavy for small or injured children.

BATTERY OPERATION
Your transmitter is operated by a rechargeable lithium polymer battery. Below you will find some advice on the use of rechargeable batteries:
- The battery of the HidnSeek GPS device cannot be replaced and must not be removed.
- Batteries may not be disassembled, thrown into fire or short-circuited.
- Never expose the HidnSeek GPS device to excessive heat such as sunshine, fire or similar source. This increases the danger of battery leakage.
- Only use the USB cable that came with your HidnSeek GPS device. The use of other cables and/or adapters might overcharge the battery and can lead to fire or explosion.

Disregarding these instructions can cause damage and possibly even cause the battery to explode.

NOTE: Some countries, states or regions have laws related to location based tracking of people, animals and objects. It’s the sole responsibility of the owner and user to abide by the law and rules in the area where the HidnSeek GPS device is used.

DISPOSAL
Batteries are hazardous waste. For the correct disposal of batteries, appropriate containers are provided at the premises of commercial battery dealers as well as local council waste disposal facilities. If you want to dispose of your HidnSeek GPS device, follow the current local provisions at the time. Information may be obtained from the local council waste disposal facility.

FUNCTIONS AND USE
In order to locate your things with HidnSeek, a PC with internet connection or a smartphone (Android, iPhone) is required. The HidnSeek GPS app can be downloaded from the Google Play Store for Android or the Apple App Store for iOS.
The HidnSeek GPS device can only be used after successful activation through a web browser.

IN ORDER TO COMPLY WITH AVIATION AUTHORITIES, SWITCH OFF YOUR HIDNSEEK DEVICE BEFORE TAKE-OFF AS THIS MAY CAUSE ELECTROMAGNETIC INTERFERENCE TO AIRCRAFT SYSTEMS.

HIDNSEEK IS A SIGFOX READY DEVICE AND NEEDS SIGFOX NETWORK COVERAGE TO OPERATE.

DECLARATION OF CONFORMITY
EMC Directive 1999/519/CE:
Short text of the Declaration of conformity: HidnSeek SAS hereby declares that the HidnSeek GPS device conforms to the fundamental
Requirements and other relevant provisions of directive 1999/519/CE.
EN 60950-1 (2006+A11/2009+A1/2010+A12/2011) IEC 60950-1 (2005+A1/2009) ETSI EN 300 220-1 V2.4.1 (2012)
ETSI EN 300 220-2 V2.4.1 (2012)
COUNCIL RECOMMENDATION N° 1999/519/CE of 12 July 1999
ETSI EN 301 489-1 (V1.9.2) - ETSI EN 301 489-3 (V1.6.1)

CE COMPLIANCE STATEMENT
This device complies with CE Rules. Operation is subject to the following 2 conditions:
1. This device may not cause harmful interference, and
2. This device must accept any interference received, including interference that may cause undesired operation.

WARNING: Changes or modifications to this unit not expressly approved by the Party responsible for compliance could void the user’s authority to operate this equipment.

NOTE: This equipment has been tested and found to comply with the limits for ETSI EN 300 220-1 V2.4.1 (2012), ETSI EN 300 220-2 V2.4.1 (2012), pursuant of the CE Rules. These limits are designed to provide reasonable protection against harmful interference in a residential installation. This equipment generates, uses and can radiate radio frequency energy and, if not installed and used in accordance with the Instructions, may cause harmful interference to radio communications.
However, there is no guarantee that interference will not occur in a particular Installation. If this equipment does cause harmful interference to radio or television reception, which can be determined by turning the equipment off and on, the user is encouraged to try to correct the interference by one or more of the following measures:
- Reorient or relocate the GPS tracker,
- Increase the separation between the equipment and the receiver.
- Consult the dealer or an experienced radio/TV technician for help.

CE RADIATION EXPOSURE STATEMENT
This requirement complies with CE radiation exposure limits set forth for an Uncontrolled environment. This equipment should be installed and operated with minimum distance 20cm between the radiator & your body.
This transmitter must not be co-located or operating in conjunction with any other antenna or transmitter.

RSS (CATEGORY I EQUIPMENT)
This device complies with Industry France license-exempt RSS standard(s). Operation is subject to the following two conditions:
1. This device may not cause interference.
2. This device must accept any interference, including interference that may cause undesired operation of the device.

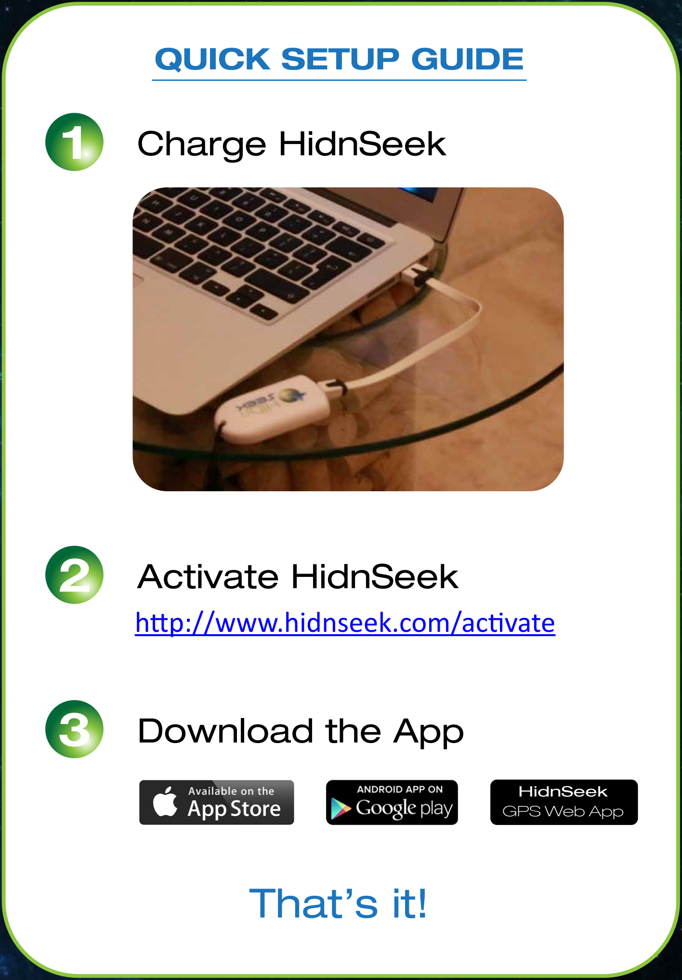
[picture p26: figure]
1 Charge HidnSeek; 2 Activate HidnSeek; 3 Download the App; QUICK SETUP GUIDE; That’s it!; HidnSeek GPS Web App; http://www.hidnseek.com/activate

1

2

3

# GETTING STARTED

## PACKAGE CONTENTS 1 HidnSeek GPS Device 1 USB Charging Cable

## Charging HidnSeek

We recommend fully charging the HidnSeek GPS device before first use. Attach the micro-USB to your HidnSeek Device then Connect the USB cable to your PC. The LED on the HidnSeek GPS device will turn yellow while the device is charging.

Once the device is fully charged, the yellow light will disappear.

## Activate HidnSeek Activation of the HidnSeek GPS device requires the

device to be powered on.

## Enter the link below into the address bar of your browser to access the HidnSeek homepage, which will guide you through the step by step activation of

your HidnSeek GPS device.

## Smartphone App To download the App from the Apple Iphone, load

up the Itunes App Store and search for ‘HidnSeek’.

## Alternatively, if you are using an Android, open up the Google play Store and start a search for

‘HidnSeek’.

## http://www.hidnseek.com/activate

# USING THE SMARTPHONE APP

## SIGN IN

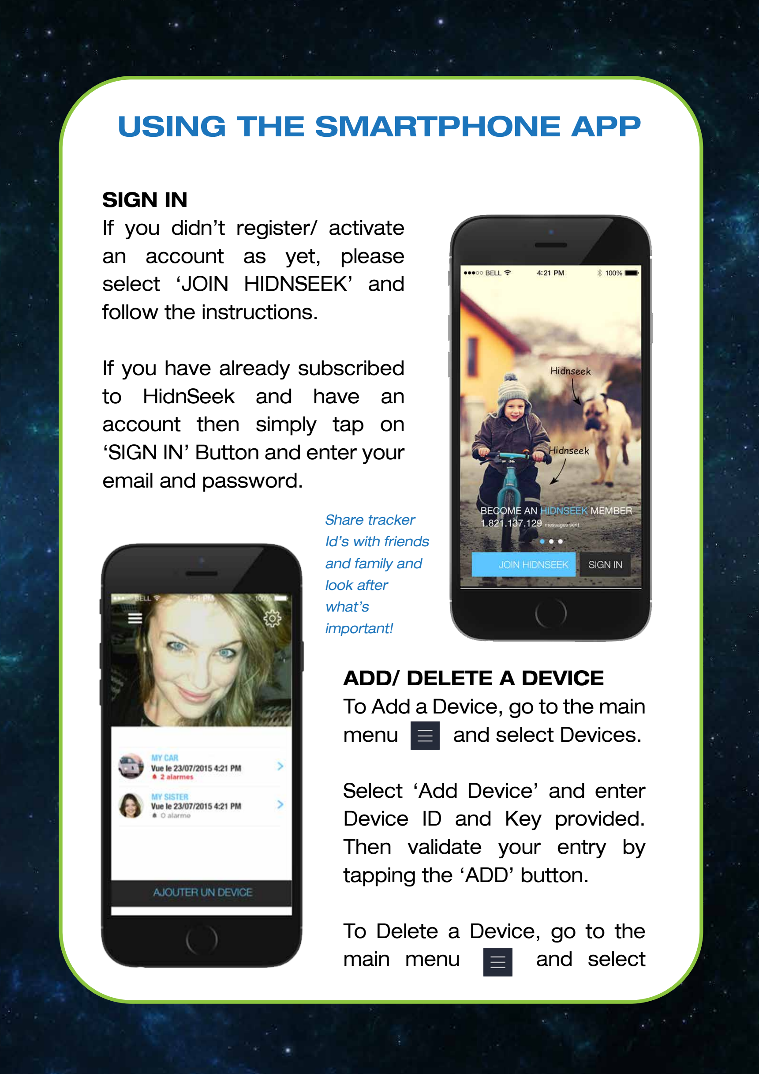
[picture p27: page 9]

## If you didn’t register/ activate an account as yet, please select ‘JOIN HIDNSEEK’ and

follow the instructions.

## If you have already subscribed to HidnSeek and have an account then simply tap on ‘SIGN IN’ Button and enter your

email and password.

## ADD/ DELETE A DEVICE To Add a Device, go to the main

menu and select Devices.

## Select ‘Add Device’ and enter

Device ID and Key provided.

## Then validate your entry by

tapping the ‘ADD’ button.

## To Delete a Device, go to the

main menu | and select

Share tracker
Id’s with friends
and family and
look after
what’s
important!

## LOCATION

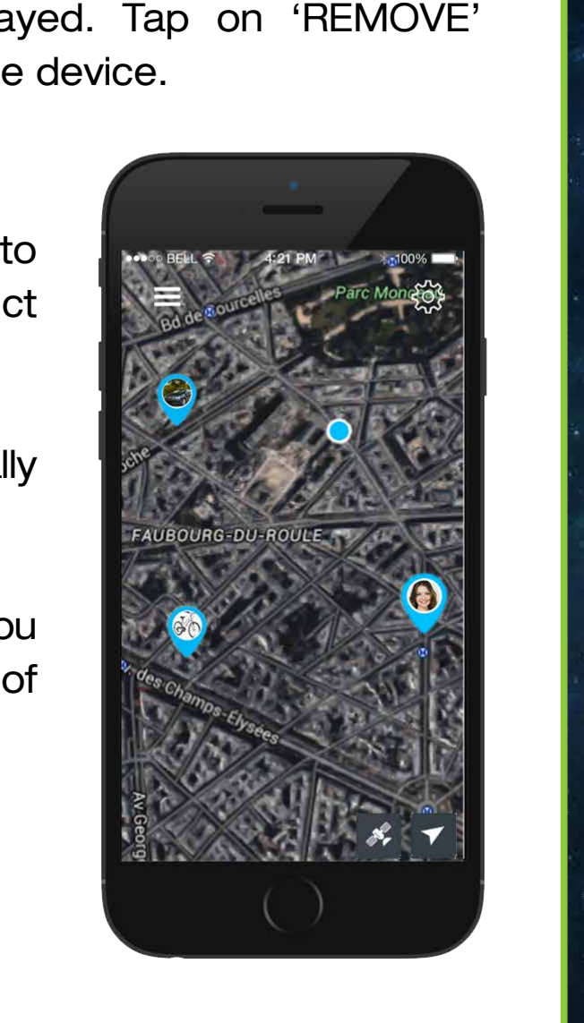
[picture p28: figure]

## To View all your Devices just go to the main Menu and select

Location.

## The view will zoom automatically

to display all your devices.

## By taping on a Device marker you can view the summary of information about your device including:

Alt (Altitude),
Cap (Direction),
Sp (Speed),
Bat (Battery level).

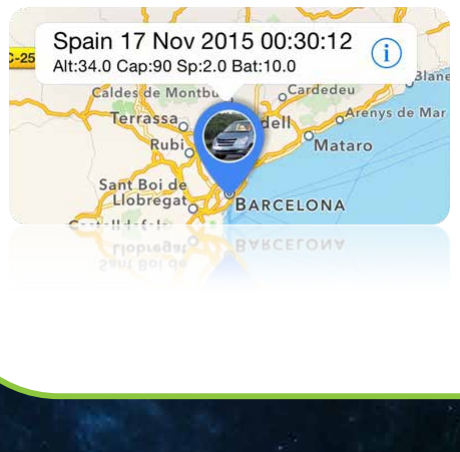
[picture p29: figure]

## Press on to display the advanced information screen

for the device.

## Devices, Then Select the Device you want to Delete. Tap on the Device settings button and scroll down until the ‘Remove’ button is displayed. Tap on ‘REMOVE’

button to confirm deletion of the device.

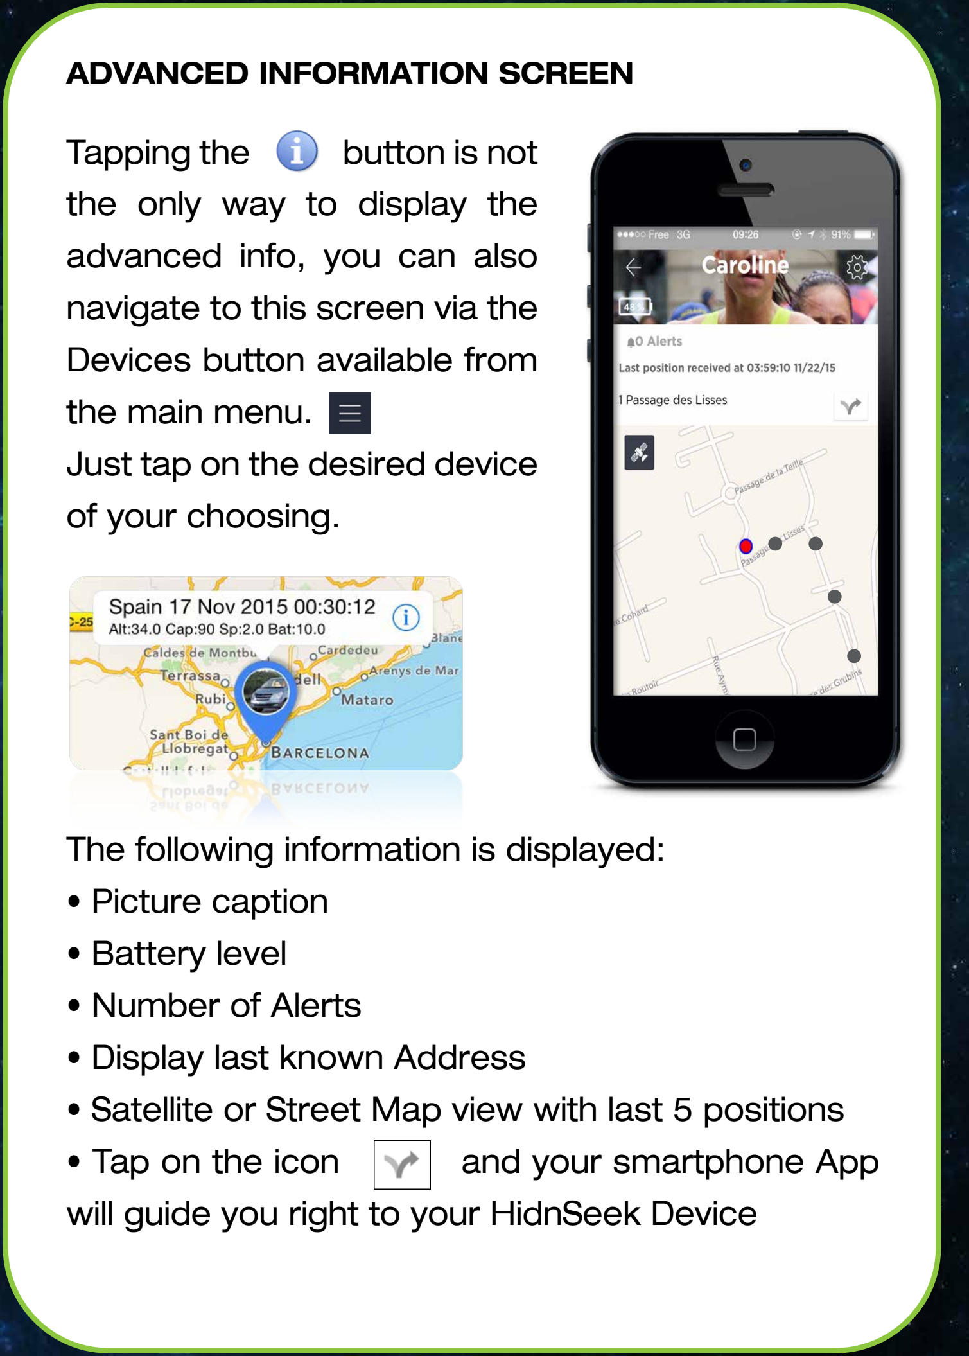
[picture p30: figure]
Tapping the; button is not; the only way to display the advanced info, you can also navigate to this screen via the Devices button available from the main menu. Just tap on the desired device of your choosing.; The following information is displayed: • Picture caption • Battery level • Number of Alerts • Display last known Address; ADVANCED INFORMATION SCREEN

## - Satellite or Street Map view with last 5 positions

- Tap on the icon | and your smartphone App

## will guide you right to your HidnSeek Device

## RENAME DEVICE

From the Device menu,

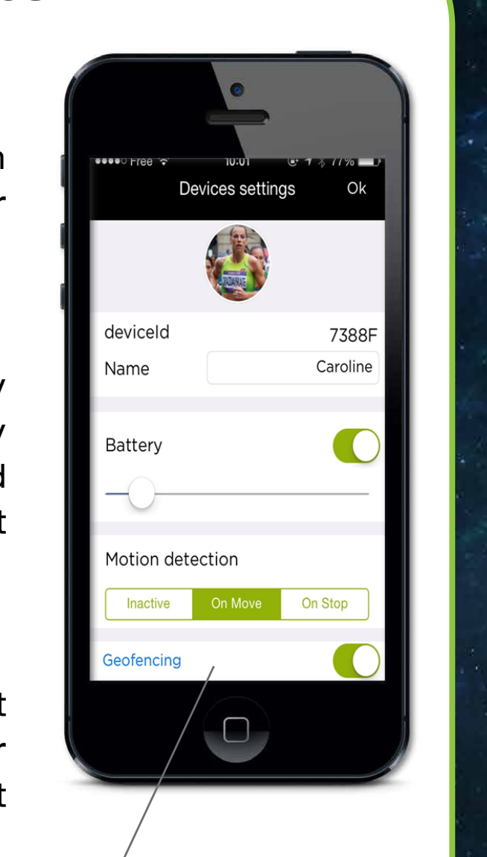
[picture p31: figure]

## select a device and then tap on Settings. You can enter or

change the device name here.

## BATTERY LEVEL To set an alert for your battery level, simply tap on the Battery button to switch on the alert and select the desired level you want

for your notification.

## MOTION DETECTION To setup Motion Detection select the option to be alerted for motion or when device does not

move.

## GEO-FENCING Tap on geofencing at the bottom of the Device Settings

menu.

## DEVICE AND ALERTS SETTINGS

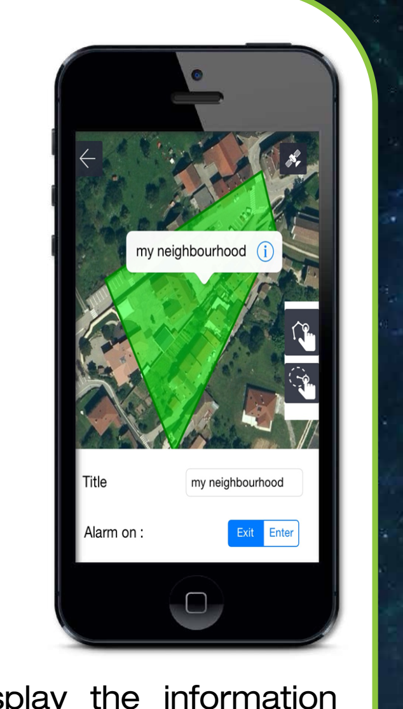
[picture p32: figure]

## CREATE A GEO-FENCE Zoom into the desired area where you want to create a geofence. Draw geofence from the options available: - point to point geo-fence - radius geo-fence

## DELETE A GEO-FENCE Touch and drag the geo-fence to the bottom of the screen where you will see the area called ‘Drop Here To

Delete’.

## GEO-FENCE SETTINGS

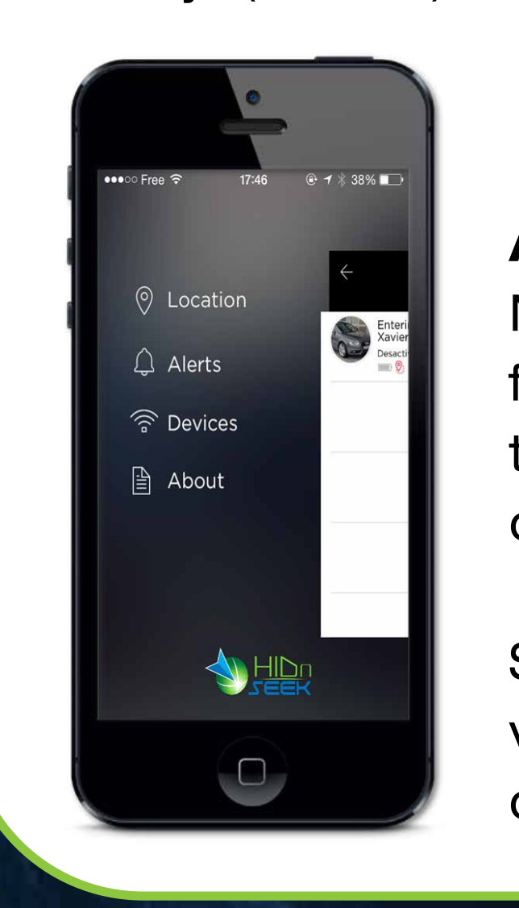
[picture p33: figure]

## ALERTS SCREEN Notifications or Alerts repository can be found by tapping the Alerts button in the main menu. A non-validated Alert is

displayed with red background.

## Swipe the Alert message and select validate to acknowledge the notification

or select clear to remove it completely.

## Tap on the geo-fence area to display the information

window.

## Enter a title for the geofence and set the alert to ‘exit’ or

‘entry’ (or both).

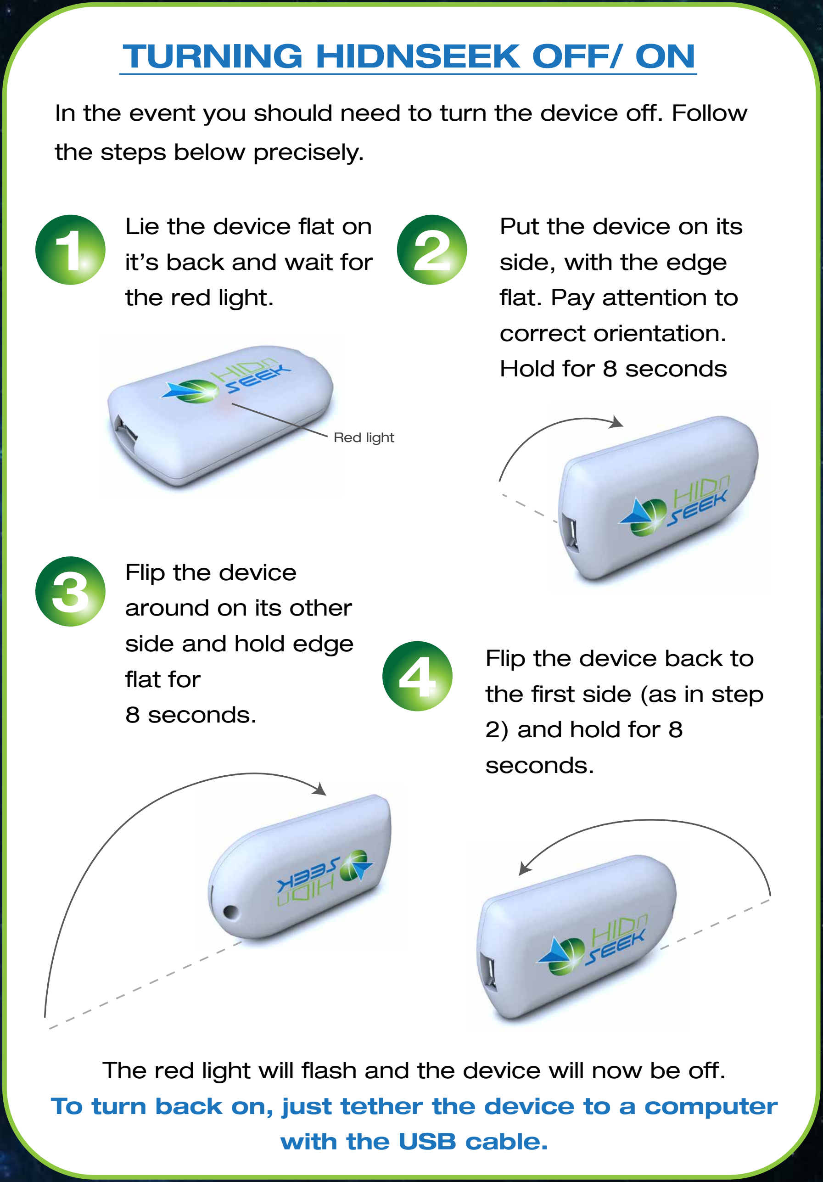
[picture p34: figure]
TURNING HIDNSEEK OFF/ ON; Lie the device flat on it’s back and wait for the red light.; Flip the device around on its other side and hold edge flat for 8 seconds.; Flip the device back to the first side (as in step 2) and hold for 8 seconds.; Put the device on its side, with the edge flat. Pay attention to correct orientation. Hold for 8 seconds; the steps below precisely.; Red light; with the USB cable.

In the event you should need to turn the device off. Follow

The red light will flash and the device will now be off.
To turn back on, just tether the device to a computer

1 2

3
4

## SPORT MODE

Lie the device flat on
it’s back and wait for
the red light.

Flip the device
around on its other
side and hold edge
flat for
8 seconds.

Lie the device flat on its back once more. After
8 seconds the device
will enter Sport mode.

Put the device on its
side, with the edge
flat. Pay attention to
correct orientation.
Hold for 8 seconds

HidnSeek by default, runs in Smart mode, which means, it will only ever update its position and all other attributes when it detects motion. It can only do this as frequently as every 10 minutes. Sport Mode puts the GPS into a constantly ready state. It will maximize the detection of satelites, regardless of whether or not it detected motion. This mode will remain active for 4 hours and then return to Smart mode.
NOTE: Sport mode will drain your battery quicker!

Red light

## DEVICE COMPONENTS

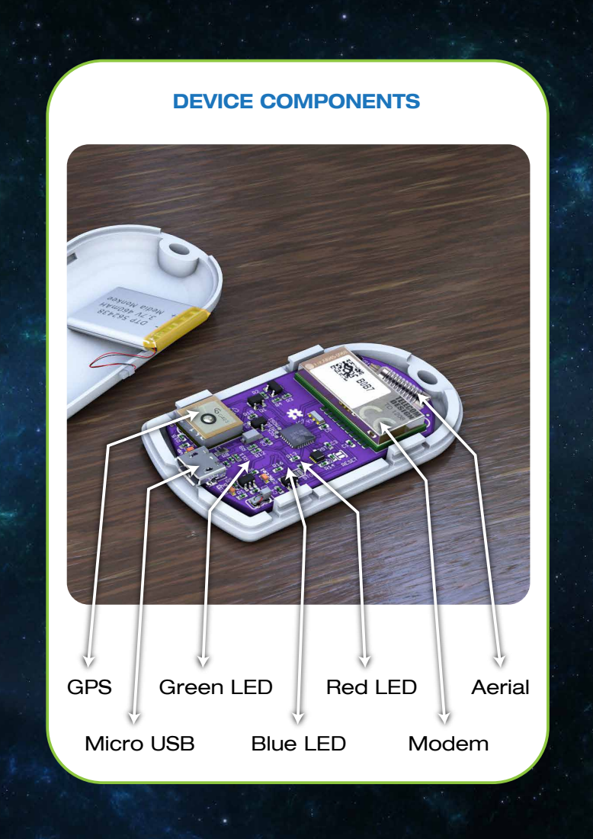
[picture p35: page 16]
GPS; Micro USB; Modem; Green LED; Blue LED; Red LED; Aerial

## LED AND DEVICE STATUS

EXAMPLE; Firmware update; Start Sequence; GPS Search; Sleep loop; Sending Position and status; 15 seconds; Every 8 seconds; 8 seconds; 16 seconds; ... 5 minutes; Repeat; GPS ok; Satellites Visible; No Satellites; No Motion; Motion; Accel ok; Option ok; Modem ok; Repeat 4 minutes; Repeat 2 minutes

Powered on by USB

Solid red for 6 seconds

5 Minute Sleep loop

2 motions ocurred within a 5 Minute Sleep loop

## SUPPORT

If you have a question or would like to submit a comment, you have the following options:

a) Read through the frequently asked questions (FAQs)
b) Contact your point of sale
c) Send us an e-mail:

PLEASE NOTE THAT DUE TO ORGANIZATIONAL REASONS WE WILL NOT ACCEPT ANY UNANNOUNCED PACKAGES SENT VIA CARRIAGE FORWARD.

contact@hidnseek.fr

http://www.hidnseek.com/faq

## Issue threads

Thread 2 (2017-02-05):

missing librairie

saisie-mobile, 2017-02-05:
hi,
The pack eagle is missing "def.h" lib to be compiled.

By the way , not sure that eagle 3.28 is the last source installed in the ST1-A sold.
thanks

saisie-mobile, 2017-02-05:
the def.h is included in fact in the Hidnseek examples supplied when you parametrize the Arduino IDE as described there - compliled with success

Closed 2017-02-05.

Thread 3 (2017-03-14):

Allumer Led / commander depuis un smartphone

Productivix, 2017-03-14:
Si je veux par exemple depuis mon smartphone allumer une led sur mon Iot , par ex la bleue (elle est jolie), on a rien prévu dans le firmware visiblement mais sur le réseau c'est possible j'imagine car il y a des messages descendants dans l'abonnement Sigfox.

Quelle est la commande Https Post et quelqu'un a un morceau de firmware que je peux ajouter SVP  , ou un lien vers la doc / github?

merci d'avance!

Closed 2021-10-10.

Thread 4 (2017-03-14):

doc API et commandes en ligne

saisie-mobile, 2017-03-14:
Bonjour,
avez-vous svp la doc sur cette commande de get (toutes les options, formes etc ?),  elle m'intéresse de  en + : comme par exemple :
https://api.hidnseek.fr/devices/73xxx/positions.json?key=xxxxxx&num=10&type_event=all
Merci d'avance !

Closed 2017-06-04.

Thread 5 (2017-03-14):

dictionnaire des messages Sigfox

saisie-mobile, 2017-03-14:
Les messages que l'on peut envoyer sont (voir def.h):

enum msgs {
  MSG_POSITION = 0, MSG_OPTION = 3, MSG_NO_MOTION = 4, MSG_NO_GPS = 5,
  MSG_MOTION_ALERT = 6, MSG_WEAK_BAT = 7

mais reste-t-il "1" et "2" de libres ?

Et avez-vous un "dictionnaire" des messages que l'on peut envoyer sur Sigfox via votre interface SVP ?
merci d'avance.

Closed 2017-06-04.

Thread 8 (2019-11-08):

High resolution mode on MMA8653

ystumtec, 2019-11-08:
Hi,
Useful library, thanks!

I noticed a couple of things when using high resolution mode combined with calls to standby() and active():
1) _x, _y and _z were declared as int8_t in the header file, but they are used as if they were int16_t in the high resolution part of the update() function. I made them int16_t and it seemed to fix high res mode.
2) not really a bug, but worth pointing out that if you put the device into standby() then you need to call begin() again after calling active() to put it back into high resolution mode (those register settings are lost on transition from standby to active).

Anyway, you saved me a bunch of work with this, so thanks.

Mark.

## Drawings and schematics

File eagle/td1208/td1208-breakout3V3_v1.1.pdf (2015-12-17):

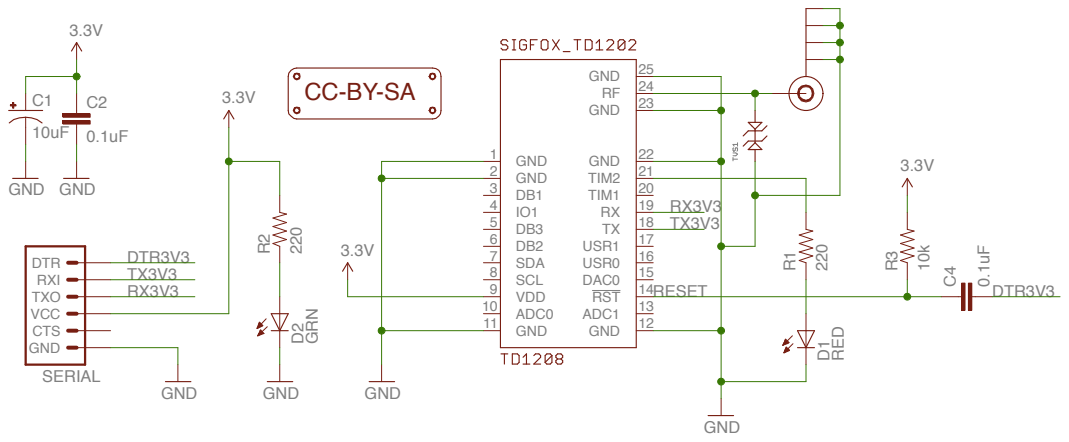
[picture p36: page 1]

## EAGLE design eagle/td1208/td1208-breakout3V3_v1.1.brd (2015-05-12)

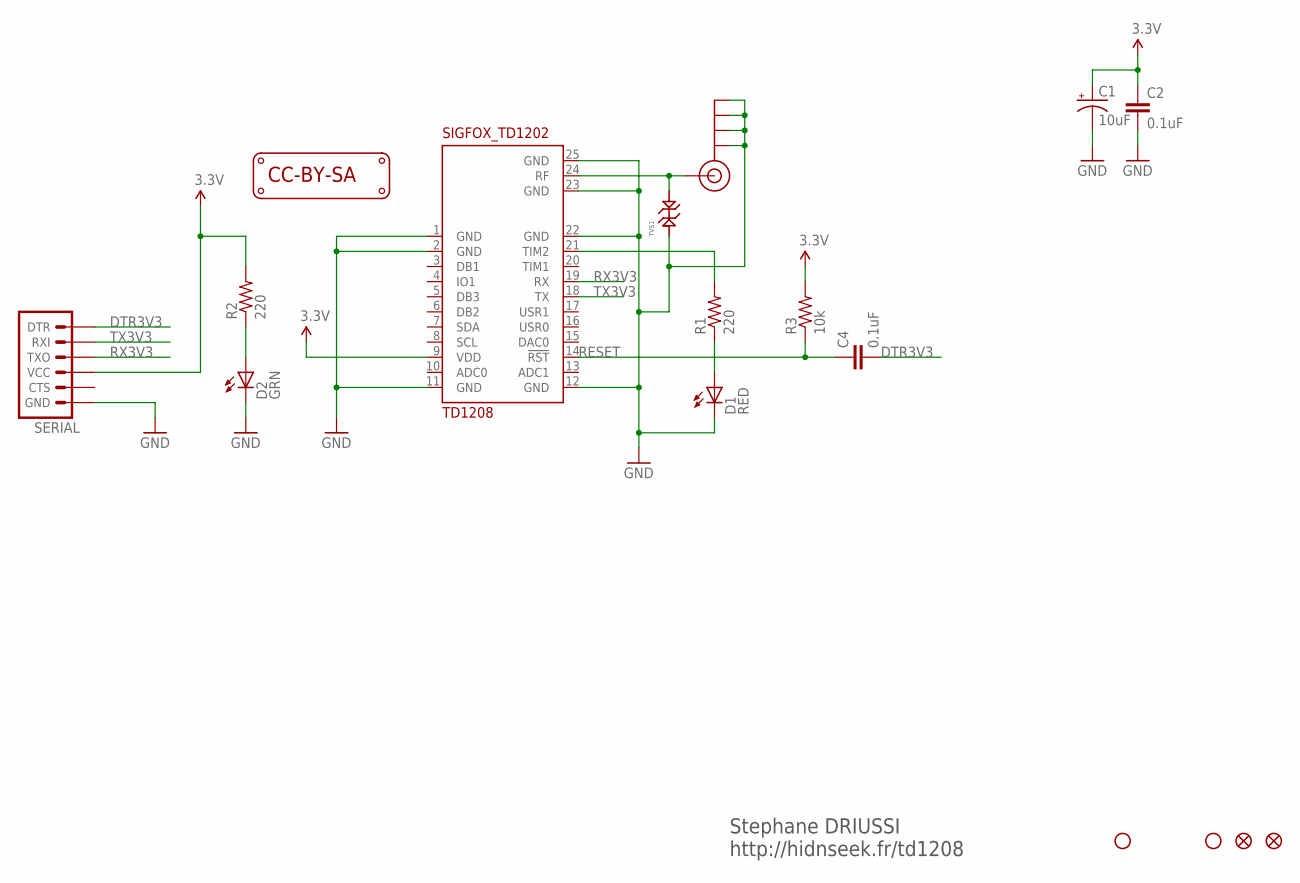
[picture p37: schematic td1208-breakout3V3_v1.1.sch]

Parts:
C1: 10uF; EIA3216; MOUSER# 74-293D106X96R3A2TE3
C2, C4: 0.1uF; 0402-CAP; MOUSER# 81-GRM155R60J104KA1D
D1: RED; CHIP-LED0603
D2: GRN; CHIP-LED0603
J$1: SMA_EDGE
LOGO1: LOGO_CC-BY-SA
R1, R2: 220; 0402-RES
R3: 10k; 0402-RES
SERIAL: ARDUINO_SERIAL_PROGRAMPTH; 1X06
TD1208: SIGFOX_TD1202; TD1202
TVS1: TVS_DIODESOD-923; SOD-923
U$5, U$11: STAND-OFF
U$7, U$16: FIDUCIAL1X2; FIDUCIAL-1X2

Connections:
3.3V: C1.A (+), C2.1, R2.2, R3.2, SERIAL.4 (VCC), TD1208.9 (VDD)
DTR3V3: C4.2, SERIAL.1 (DTR)
GND: C1.C (-), C2.2, D1.C, D2.C, J$1.GND@0 (GND), J$1.GND@1 (GND), J$1.GND@2 (GND), J$1.GND@3 (GND), SERIAL.6 (GND), TD1208.1 (GND), TD1208.2 (GND), TD1208.11 (GND), TD1208.12 (GND), TD1208.22 (GND), TD1208.23 (GND), TD1208.25 (GND), TVS1.P$1
unnamed: D2.A, R2.1
unnamed: J$1.SIG (SIGNAL), TD1208.24 (RF), TVS1.P$2
unnamed: R1.2, TD1208.21 (TIM2)
unnamed: D1.A, R1.1
RESET: C4.1, R3.1, TD1208.14 (!RST)
RX3V3: SERIAL.3 (TXO), TD1208.19 (RX)
TX3V3: SERIAL.2 (RXI), TD1208.18 (TX)

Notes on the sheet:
Stephane DRIUSSI http://hidnseek.fr/td1208

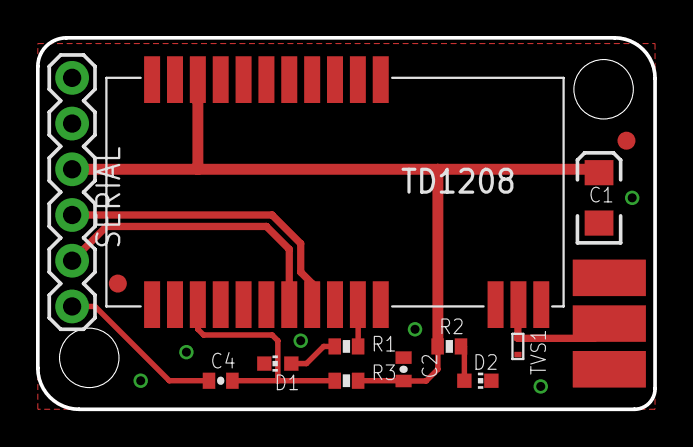
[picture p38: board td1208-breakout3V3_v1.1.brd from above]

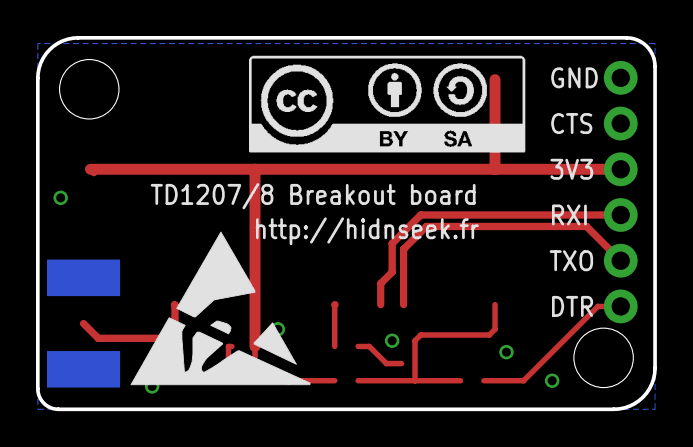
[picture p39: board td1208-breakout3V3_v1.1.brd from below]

Board: 2 copper layers, 34.3 x 20.6 mm, 18 parts (2 on the bottom side), 10 nets.

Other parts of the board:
U$1: ESD_10.00

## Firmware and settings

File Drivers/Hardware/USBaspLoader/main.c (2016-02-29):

/* Name: main.c
 * Project: USBaspLoader
 * Author: Christian Starkjohann
 * Creation Date: 2007-12-08
 * Tabsize: 4
 * Copyright: (c) 2007 by OBJECTIVE DEVELOPMENT Software GmbH
 * License: GNU GPL v2 (see License.txt)
 * This Revision: $Id$
 */

#include <avr/io.h>
#include <avr/interrupt.h>
#include <avr/pgmspace.h>
#include <avr/wdt.h>
#include <avr/boot.h>
#include <avr/eeprom.h>
#include <util/delay.h>
#include <string.h>

static void leaveBootloader() __attribute__((__noreturn__));

#include "bootloaderconfig.h"
#include "usbdrv/usbdrv.c"

/* ------------------------------------------------------------------------ */

/* Request constants used by USBasp */
#define USBASP_FUNC_CONNECT         1
#define USBASP_FUNC_DISCONNECT      2
#define USBASP_FUNC_TRANSMIT        3
#define USBASP_FUNC_READFLASH       4
#define USBASP_FUNC_ENABLEPROG      5
#define USBASP_FUNC_WRITEFLASH      6
#define USBASP_FUNC_READEEPROM      7
#define USBASP_FUNC_WRITEEEPROM     8
#define USBASP_FUNC_SETLONGADDRESS  9

/* ------------------------------------------------------------------------ */

#ifndef ulong
#   define ulong    unsigned long
#endif
#ifndef uint
#   define uint     unsigned int
#endif

/* defaults if not in config file: */
#ifndef USING_PUSHBUTTON
#   define USING_PUSHBUTTON 0
#endif
#ifndef TIMEOUT_ENABLED
#   define TIMEOUT_ENABLED 0
#endif
#ifndef TIMEOUT_DURATION
#   define TIMEOUT_DURATION 20
#endif
#ifndef HAVE_EEPROM_PAGED_ACCESS
#   define HAVE_EEPROM_PAGED_ACCESS 0
#endif
#ifndef HAVE_EEPROM_BYTE_ACCESS
#   define HAVE_EEPROM_BYTE_ACCESS  0
#endif
#ifndef BOOTLOADER_CAN_EXIT
#   define  BOOTLOADER_CAN_EXIT     0
#endif

/* allow compatibility with avrusbboot's bootloaderconfig.h: */
#ifdef BOOTLOADER_INIT
#   define bootLoaderInit()         BOOTLOADER_INIT
#   define bootLoaderExit()
#endif
#ifdef BOOTLOADER_CONDITION
#   define bootLoaderCondition()    BOOTLOADER_CONDITION
#endif

/* device compatibility: */
#ifndef TIFR1    /* ATMega8 uses TIFR instead of TIFR1 */
#   define TIFR1     TIFR
#endif
#ifndef GICR    /* ATMega*8 don't have GICR, use MCUCR instead */
#   define GICR     MCUCR
#endif

/* ------------------------------------------------------------------------ */

#if (FLASHEND) > 0xffff /* we need long addressing */
#   define CURRENT_ADDRESS  currentAddress.l
#   define addr_t           ulong
#else
#   define CURRENT_ADDRESS  currentAddress.w[0]
#   define addr_t           uint
#endif

typedef union longConverter{
    addr_t  l;
    uint    w[sizeof(addr_t)/2];
    uchar   b[sizeof(addr_t)];
}longConverter_t;

#if TIMEOUT_ENABLED
static uint8_t          inactivity_timer_nsec;
#endif
static uchar            requestBootLoaderExit;
static longConverter_t  currentAddress; /* in bytes */
static uchar            bytesRemaining;
static uchar            isLastPage;
#if HAVE_EEPROM_PAGED_ACCESS
static uchar            currentRequest;
#else
static const uchar      currentRequest = 0;
#endif

static const uchar  signatureBytes[4] = {
#ifdef SIGNATURE_BYTES
    SIGNATURE_BYTES
#elif defined (__AVR_ATmega8__) || defined (__AVR_ATmega8HVA__)
    0x1e, 0x93, 0x07, 0
#elif defined (__AVR_ATmega48__) || defined (__AVR_ATmega48P__)
    0x1e, 0x92, 0x05, 0
#elif defined (__AVR_ATmega88__) || defined (__AVR_ATmega88P__)
    0x1e, 0x93, 0x0a, 0
#elif defined (__AVR_ATmega168__) || defined (__AVR_ATmega168P__)
    0x1e, 0x94, 0x06, 0
#elif defined (__AVR_ATmega328P__)
    0x1e, 0x95, 0x0f, 0
#else
#   error "Device signature is not known, please edit main.c!"
#endif
};

/* ------------------------------------------------------------------------ */

#if TIMEOUT_ENABLED
static void inactivity_timer_start(void);
static void inactivity_timer_stop(void);
#endif
static void (*nullVector)(void) __attribute__((__noreturn__));

/* ------------------------------------------------------------------------ */

static void leaveBootloader()
{
    DBG1(0x01, 0, 0);
    bootLoaderExit();
    cli();
    USB_INTR_ENABLE = 0;
    USB_INTR_CFG = 0;       /* also reset config bits */
    GICR = (1 << IVCE);     /* enable change of interrupt vectors */
    GICR = (0 << IVSEL);    /* move interrupts to application flash section */
/* We must go through a global function pointer variable instead of writing
 *  ((void (*)(void))0)();
 * because the compiler optimizes a constant 0 to "rcall 0" which is not
 * handled correctly by the assembler.
 */
    nullVector();
}

/* ------------------------------------------------------------------------ */

uchar   usbFunctionSetup(uchar data[8])
{
usbRequest_t    *rq = (void *)data;
uchar           len = 0;
static uchar    replyBuffer[4];

#if TIMEOUT_ENABLED
    inactivity_timer_stop();
#endif

    usbMsgPtr = (usbMsgPtr_t)replyBuffer;
    if(rq->bRequest == USBASP_FUNC_TRANSMIT){   /* emulate parts of ISP protocol */
        uchar rval = 0;
        usbWord_t address;
        address.bytes[1] = rq->wValue.bytes[1];
        address.bytes[0] = rq->wIndex.bytes[0];
        if(rq->wValue.bytes[0] == 0x30){        /* read signature */
            rval = rq->wIndex.bytes[0] & 3;
            rval = signatureBytes[rval];
#if HAVE_EEPROM_BYTE_ACCESS
        }else if(rq->wValue.bytes[0] == 0xa0){  /* read EEPROM byte */
            rval = eeprom_read_byte((void *)address.word);
        }else if(rq->wValue.bytes[0] == 0xc0){  /* write EEPROM byte */
            eeprom_write_byte((void *)address.word, rq->wIndex.bytes[1]);
#endif
#if HAVE_CHIP_ERASE
        }else if(rq->wValue.bytes[0] == 0xac && rq->wValue.bytes[1] == 0x80){  /* chip erase */
            addr_t addr;
            for(addr = 0; addr < FLASHEND + 1 - 2048; addr += SPM_PAGESIZE) {
                /* wait and erase page */
                DBG1(0x33, 0, 0);
#   ifndef NO_FLASH_WRITE
                boot_spm_busy_wait();
                cli();
                boot_page_erase(addr);
                sei();
#   endif
            }
#endif
        }else{
            /* ignore all others, return default value == 0 */
        }
        replyBuffer[3] = rval;
        len = 4;
    }else if(rq->bRequest == USBASP_FUNC_ENABLEPROG){
        /* replyBuffer[0] = 0; is never touched and thus always 0 which means success */
        len = 1;
    }else if(rq->bRequest >= USBASP_FUNC_READFLASH && rq->bRequest <= USBASP_FUNC_SETLONGADDRESS){
        currentAddress.w[0] = rq->wValue.word;
        if(rq->bRequest == USBASP_FUNC_SETLONGADDRESS){
#if (FLASHEND) > 0xffff
            currentAddress.w[1] = rq->wIndex.word;
#endif
        }else{
            bytesRemaining = rq->wLength.bytes[0];
            /* if(rq->bRequest == USBASP_FUNC_WRITEFLASH) only evaluated during writeFlash anyway */
            isLastPage = rq->wIndex.bytes[1] & 0x02;
#if HAVE_EEPROM_PAGED_ACCESS
            currentRequest = rq->bRequest;
#endif
            len = 0xff; /* hand over to usbFunctionRead() / usbFunctionWrite() */
        }
#if BOOTLOADER_CAN_EXIT
    }else if(rq->bRequest == USBASP_FUNC_DISCONNECT){
        requestBootLoaderExit = 1;      /* allow proper shutdown/close of connection */
#endif
    }else{
        /* ignore: USBASP_FUNC_CONNECT */
    }

#if TIMEOUT_ENABLED
    inactivity_timer_start();
#endif

    return len;
}

uchar usbFunctionWrite(uchar *data, uchar len)
{
uchar   isLast;

#if TIMEOUT_ENABLED
    inactivity_timer_stop();
#endif

    DBG1(0x31, (void *)&currentAddress.l, 4);
    if(len > bytesRemaining)
        len = bytesRemaining;
    bytesRemaining -= len;
    isLast = bytesRemaining == 0;
    if(currentRequest >= USBASP_FUNC_READEEPROM){
        uchar i;
        for(i = 0; i < len; i++){
            eeprom_write_byte((void *)(currentAddress.w[0]++), *data++);
        }
    }else{
        uchar i;
        for(i = 0; i < len;){
#if !HAVE_CHIP_ERASE
            if((currentAddress.w[0] & (SPM_PAGESIZE - 1)) == 0){    /* if page start: erase */
                DBG1(0x33, 0, 0);
#   ifndef NO_FLASH_WRITE
                cli();
                boot_page_erase(CURRENT_ADDRESS);   /* erase page */
                sei();
                boot_spm_busy_wait();               /* wait until page is erased */
#   endif
            }
#endif
            i += 2;
            DBG1(0x32, 0, 0);
            cli();
            boot_page_fill(CURRENT_ADDRESS, *(short *)data);
            sei();
            CURRENT_ADDRESS += 2;
            data += 2;
            /* write page when we cross page boundary or we have the last partial page */
            if((currentAddress.w[0] & (SPM_PAGESIZE - 1)) == 0 || (isLast && i >= len && isLastPage)){
                DBG1(0x34, 0, 0);
#ifndef NO_FLASH_WRITE
                cli();
                boot_page_write(CURRENT_ADDRESS - 2);
                sei();
                boot_spm_busy_wait();
                cli();
                boot_rww_enable();
                sei();
#endif
            }
        }
        DBG1(0x35, (void *)&currentAddress.l, 4);
    }

#if TIMEOUT_ENABLED
    inactivity_timer_start();
#endif

    return isLast;
}

uchar usbFunctionRead(uchar *data, uchar len)
{
uchar   i;

#if TIMEOUT_ENABLED
    inactivity_timer_stop();
#endif

    if(len > bytesRemaining)
        len = bytesRemaining;
    bytesRemaining -= len;
    for(i = 0; i < len; i++){
        if(currentRequest >= USBASP_FUNC_READEEPROM){
            *data = eeprom_read_byte((void *)currentAddress.w[0]);
        }else{
            *data = pgm_read_byte((void *)CURRENT_ADDRESS);
        }
        data++;
        CURRENT_ADDRESS++;
    }

#if TIMEOUT_ENABLED
    inactivity_timer_start();
#endif

    return len;
}

/* ------------------------------------------------------------------------ */

#if TIMEOUT_ENABLED
static void inactivity_timer_start(void)
{
    inactivity_timer_nsec = 0;
    TCNT1 = 0; // reset timer to 0
    TCCR1B |= ((1 << CS12) | (1 << CS10));    // start timer, 1024 prescale
}

static void inactivity_timer_stop(void)
{
    inactivity_timer_nsec = 0;
    TCCR1B &= ~((1 << CS12) | (1 << CS11) | (1 << CS10)); // stop timer
}
#endif

/* ------------------------------------------------------------------------ */

static void initForUsbConnectivity(void)
{
uchar   i = 0;

    usbInit();
    /* enforce USB re-enumerate: */
    usbDeviceDisconnect();  /* do this while interrupts are disabled */
    while(--i){         /* fake USB disconnect for > 250 ms */
        wdt_reset();
        _delay_ms(1);
    }
    usbDeviceConnect();

#if TIMEOUT_ENABLED
    TCCR1B |= (1 << WGM12); // put timer1 in CTC mode
    OCR1A = F_CPU/1024; // number of prescaled ticks per second
#endif

    sei();
}

int __attribute__((noreturn)) main(void)
{
    /* initialize  */
    wdt_disable();      /* main app may have enabled watchdog */
    bootLoaderInit();
    odDebugInit();
    DBG1(0x00, 0, 0);
#ifndef NO_FLASH_WRITE
    GICR = (1 << IVCE);  /* enable change of interrupt vectors */
    GICR = (1 << IVSEL); /* move interrupts to boot flash section */
#endif
    if(bootLoaderCondition()){
        uchar i = 0, j = 0;
        initForUsbConnectivity();
        do{
            usbPoll();
#if TIMEOUT_ENABLED
            PORTD |= (1 << PD7);  // turn on red LED
            if(--i == 0){
                if(--j == 0){
                    inactivity_timer_nsec++;
                    DDRD ^= ( 1 << PD7 );
                }
            }
            /* if (TIFR1 & (1 << OCF1A)){
                inactivity_timer_nsec++;
                TIFR1 = (1 << OCF1A); // clear interrupt
                DDRD |= (1 << PD7);  // turn on red LED
                PORTD ^= ( 1 << PD7 );
            } */
            if (inactivity_timer_nsec >= TIMEOUT_DURATION){
                break;
            }
#endif
#if BOOTLOADER_CAN_EXIT
            if(requestBootLoaderExit){
                if(--i == 0){
                    if(--j == 0)
                        break;
                }
            }
#endif
        }while(bootLoaderCondition() || USING_PUSHBUTTON);  /* main event loop */
    }
    leaveBootloader();
}

/* ------------------------------------------------------------------------ */

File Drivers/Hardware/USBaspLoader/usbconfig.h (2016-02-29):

/* Name: usbconfig.h
 * Project: V-USB, virtual USB port for Atmel's(r) AVR(r) microcontrollers
 * Author: Christian Starkjohann
 * Creation Date: 2005-04-01
 * Tabsize: 4
 * Copyright: (c) 2005 by OBJECTIVE DEVELOPMENT Software GmbH
 * License: GNU GPL v2 (see License.txt), GNU GPL v3 or proprietary (CommercialLicense.txt)
 * This Revision: $Id$
 */

#ifndef __usbconfig_h_included__
#define __usbconfig_h_included__

/* YOU SHOULD NOT NEED TO MODIFY THIS FILE! All configurations are supposed
 * to go into bootloaderconfig.h!
 */

/* ---------------------------- Hardware Config ---------------------------- */

/* All the port and pin assignments, as well as the clock speed and CRC
   setting are now in bootloaderconfig.h: */

#include "bootloaderconfig.h"

/* --------------------------- Functional Range ---------------------------- */

#define USB_CFG_HAVE_INTRIN_ENDPOINT    1
/* Define this to 1 if you want to compile a version with two endpoints: The
 * default control endpoint 0 and an interrupt-in endpoint (any other endpoint
 * number).
 */
#define USB_CFG_HAVE_INTRIN_ENDPOINT3   0
/* Define this to 1 if you want to compile a version with three endpoints: The
 * default control endpoint 0, an interrupt-in endpoint 3 (or the number
 * configured below) and a catch-all default interrupt-in endpoint as above.
 * You must also define USB_CFG_HAVE_INTRIN_ENDPOINT to 1 for this feature.
 */
#define USB_CFG_EP3_NUMBER              3
/* If the so-called endpoint 3 is used, it can now be configured to any other
 * endpoint number (except 0) with this macro. Default if undefined is 3.
 */
/* #define USB_INITIAL_DATATOKEN           USBPID_DATA1 */
/* The above macro defines the startup condition for data toggling on the
 * interrupt/bulk endpoints 1 and 3. Defaults to USBPID_DATA1.
 * Since the token is toggled BEFORE sending any data, the first packet is
 * sent with the oposite value of this configuration!
 */
#define USB_CFG_IMPLEMENT_HALT          0
/* Define this to 1 if you also want to implement the ENDPOINT_HALT feature
 * for endpoint 1 (interrupt endpoint). Although you may not need this feature,
 * it is required by the standard. We have made it a config option because it
 * bloats the code considerably.
 */
#define USB_CFG_SUPPRESS_INTR_CODE      0
/* Define this to 1 if you want to declare interrupt-in endpoints, but don't
 * want to send any data over them. If this macro is defined to 1, functions
 * usbSetInterrupt() and usbSetInterrupt3() are omitted. This is useful if
 * you need the interrupt-in endpoints in order to comply to an interface
 * (e.g. HID), but never want to send any data. This option saves a couple
 * of bytes in flash memory and the transmit buffers in RAM.
 */
#define USB_CFG_INTR_POLL_INTERVAL      10
/* If you compile a version with endpoint 1 (interrupt-in), this is the poll
 * interval. The value is in milliseconds and must not be less than 10 ms for
 * low speed devices.
 */
#define USB_CFG_IS_SELF_POWERED         0
/* Define this to 1 if the device has its own power supply. Set it to 0 if the
 * device is powered from the USB bus.
 */
#define USB_CFG_MAX_BUS_POWER           250
/* Set this variable to the maximum USB bus power consumption of your device.
 * The value is in milliamperes. [It will be divided by two since USB
 * communicates power requirements in units of 2 mA.]
 */
#define USB_CFG_IMPLEMENT_FN_WRITE      1
/* Set this to 1 if you want usbFunctionWrite() to be called for control-out
 * transfers. Set it to 0 if you don't need it and want to save a couple of
 * bytes.
 */
#define USB_CFG_IMPLEMENT_FN_READ       1
/* Set this to 1 if you need to send control replies which are generated
 * "on the fly" when usbFunctionRead() is called. If you only want to send
 * data from a static buffer, set it to 0 and return the data from
 * usbFunctionSetup(). This saves a couple of bytes.
 */
#define USB_CFG_IMPLEMENT_FN_WRITEOUT   0
/* Define this to 1 if you want to use interrupt-out (or bulk out) endpoints.
 * You must implement the function usbFunctionWriteOut() which receives all
 * interrupt/bulk data sent to any endpoint other than 0. The endpoint number
 * can be found in 'usbRxToken'.
 */
#define USB_CFG_HAVE_FLOWCONTROL        0
/* Define this to 1 if you want flowcontrol over USB data. See the definition
 * of the macros usbDisableAllRequests() and usbEnableAllRequests() in
 * usbdrv.h.
 */
#define USB_CFG_DRIVER_FLASH_PAGE       0
/* If the device has more than 64 kBytes of flash, define this to the 64 k page
 * where the driver's constants (descriptors) are located. Or in other words:
 * Define this to 1 for boot loaders on the ATMega128.
 */
#define USB_CFG_LONG_TRANSFERS          0
/* Define this to 1 if you want to send/receive blocks of more than 254 bytes
 * in a single control-in or control-out transfer. Note that the capability
 * for long transfers increases the driver size.
 */
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

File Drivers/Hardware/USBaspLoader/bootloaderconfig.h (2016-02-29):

/* Name: bootloaderconfig.h
 * Project: USBaspLoader
 * Author: Christian Starkjohann
 * Creation Date: 2007-12-08
 * Tabsize: 4
 * Copyright: (c) 2007 by OBJECTIVE DEVELOPMENT Software GmbH
 * License: GNU GPL v2 (see License.txt)
 * This Revision: $Id$
 */

#ifndef __bootloaderconfig_h_included__
#define __bootloaderconfig_h_included__

/*
General Description:
This file (together with some settings in Makefile) configures the boot loader
according to the hardware.

This file contains (besides the hardware configuration normally found in
usbconfig.h) two functions or macros: bootLoaderInit() and
bootLoaderCondition(). Whether you implement them as macros or as static
inline functions is up to you, decide based on code size and convenience.

bootLoaderInit() is called as one of the first actions after reset. It should
be a minimum initialization of the hardware so that the boot loader condition
can be read. This will usually consist of activating a pull-up resistor for an
external jumper which selects boot loader mode.

bootLoaderCondition() is called immediately after initialization and in each
main loop iteration. If it returns TRUE, the boot loader will be active. If it
returns FALSE, the boot loader jumps to address 0 (the loaded application)
immediately.

For compatibility with Thomas Fischl's avrusbboot, we also support the macro
names BOOTLOADER_INIT and BOOTLOADER_CONDITION for this functionality. If
these macros are defined, the boot loader usees them.
*/

/* ---------------------------- Hardware Config ---------------------------- */

#define USB_CFG_IOPORTNAME      D
/* This is the port where the USB bus is connected. When you configure it to
 * "B", the registers PORTB, PINB and DDRB will be used.
 */
#define USB_CFG_DMINUS_BIT      4
/* This is the bit number in USB_CFG_IOPORT where the USB D- line is connected.
 * This may be any bit in the port.
 */
#define USB_CFG_DPLUS_BIT       2
/* This is the bit number in USB_CFG_IOPORT where the USB D+ line is connected.
 * This may be any bit in the port. Please note that D+ must also be connected
 * to interrupt pin INT0!
 */
#define USB_CFG_CLOCK_KHZ       (F_CPU/1000)
/* Clock rate of the AVR in MHz. Legal values are 12000, 16000 or 16500.
 * The 16.5 MHz version of the code requires no crystal, it tolerates +/- 1%
 * deviation from the nominal frequency. All other rates require a precision
 * of 2000 ppm and thus a crystal!
 * Default if not specified: 12 MHz
 */

/* ----------------------- Optional Hardware Config ------------------------ */

/* #define USB_CFG_PULLUP_IOPORTNAME   D */
/* If you connect the 1.5k pullup resistor from D- to a port pin instead of
 * V+, you can connect and disconnect the device from firmware by calling
 * the macros usbDeviceConnect() and usbDeviceDisconnect() (see usbdrv.h).
 * This constant defines the port on which the pullup resistor is connected.
 */
/* #define USB_CFG_PULLUP_BIT          4 */
/* This constant defines the bit number in USB_CFG_PULLUP_IOPORT (defined
 * above) where the 1.5k pullup resistor is connected. See description
 * above for details.
 */
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

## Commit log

2015-02-19 hidnSeek Eagle library
    Add freescale 3-Axis 10-bit Digital Accelerometer MMA8653
2015-12-15 Windows drivers
    windows driver from Thomas Fischl
2016-01-03 firmware update for 3.28 board
    - Fix issue with modem ID that contain 73 value
    - Improve detection of airplane mode
    - Add sport mode feature
2016-02-12 Add Windows 8.1 and 10 USBasp driver
    Driver is now digitally signed.
2016-02-17 Add Accelerometer example
    Led Red blink when motion, Led Blue blink otherwise
2016-02-27 Autostop demo
    To avoid battery issue, the demo stop itself after 51 seconds of non
    motion.
2016-03-20 Minor change
    - Comments formatted
    - New calibration algorithm, reset calibration value after each restart
    - Remove 12mV to compensate battery internal resistance during charge
2016-03-31 fix include wire path
2016-04-07 fix active configuration
    Register REG2 need to be updated before entering in active mode
    Change to ODR at 6Hz and Low Power Mode, save 15uA
2016-04-23 Optimize library, code and power consumption
    Power consumption in sleep mode is reduced to 110uA that allow up to 3
    months more of autonomy.
2016-06-10 New example for dog tracking
    This release activate dog tracking instead of sportMode. The tracker
    start to get the current position and store it has center of the
    geo-fencing.
2016-08-03 Corrected time for isReady()
    Time was originally set to 60000 milliseconds (1 minute) in the
    isReady() function. Unlicensed Frequency regulation limits protocol
    from transmitting more than 144 times per day. Increased value to
    600000 milliseconds (10 minutes).
2017-09-07 Update HidnSeek_v3_28.hex for RevA board
2017-09-07 Update and rename firmware for RevB board

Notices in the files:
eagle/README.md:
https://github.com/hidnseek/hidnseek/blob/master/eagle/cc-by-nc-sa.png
